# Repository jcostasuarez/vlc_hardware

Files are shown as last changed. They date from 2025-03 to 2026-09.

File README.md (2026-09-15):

# VLC Hardware — Comunicación por Luz Visible

Hardware abierto (KiCad) de una cadena de comunicación por luz visible (VLC):
transmisor óptico, receptor óptico de alta sensibilidad y placas de
acondicionamiento RF. Proyecto final de la carrera de Ingeniería Electrónica,
UTN FRBA.

Cada placa es un módulo independiente que se interconecta con cables coaxiales
SMA de 50 Ω. Todos los proyectos son **autocontenidos**: las huellas y los
símbolos están embebidos y copiados en la biblioteca local de cada proyecto, de
modo que se abren y verifican sin depender de bibliotecas externas.

## Arquitectura

```
Transmisor:   PRE ──► AMP ─┐
                         ├──► LED ──► (espacio libre, luz IR)
              PRE ──► FCA ─┘

Receptor:     PD ──► TIA ──► rx_amp ──► osciloscopio / ADC
```

- **TX**: `PRE` (red de preénfasis) excita a `AMP` **o** a `FCA`; el driver
  elegido alimenta la placa `LED`.
- **RX**: `PD` (fotodiodo + bias) entra a **una sola** placa `TIA`
  (`LMH34400` **o** `LTC6268-10`) y su salida pasa por `rx_amp`.
- **No instalar ambas TIA** en la misma cadena.

Detalle de cableado, alimentación y layout en
[docs/INTEGRACION_MODULAR.md](docs/INTEGRACION_MODULAR.md).

## Placas

| Proyecto | Ruta | Función |
|---|---|---|
| `rx_amp` | `Receiver/AMP/` | Amplificador receptor BGA616, SMA de entrada/salida y alimentación |
| `PD` | `Receiver/PD/` | Adaptador de fotodiodos PDB-C154SM / S5971 / SFH203, SMA y bias |
| `LMH34400` | `Receiver/TIA/LMH34400/` | TIA LMH34400 con entradas PD, salida RF y ALC |
| `LTC6268-10` | `Receiver/TIA/LTC6268-10/` | TIA LTC6268-10 con entrada PD y salida RF |
| `tx_amplifier` | `Transmitter/AMP/` | Amplificador de transmisión con SMA y alimentación de 3,3 V |
| `LumiCom_Transmitter` | `Transmitter/FCA/` | Amplificador/filtro de dos canales con OPA2675 (4 capas) |
| `LED` | `Transmitter/LED/` | Driver/emisor óptico IR, bobina y conectividad RF |
| `preenfasis` | `Transmitter/PRE/` | Red RF de preénfasis (variantes microstrip/CPW) |

## Estructura del repositorio

```
Receiver/AMP/            rx_amp.kicad_{pcb,sch} + library/
Receiver/PD/             PD.kicad_{pcb,sch} + Library/
Receiver/TIA/LMH34400/   LMH34400.kicad_{pcb,sch} + Library/
Receiver/TIA/LTC6268-10/ LTC6268-10.kicad_{pcb,sch} + Library/
Transmitter/AMP/         tx_amplifier.kicad_{pcb,sch} + footprints/
Transmitter/FCA/         LumiCom_Transmitter.kicad_{pcb,sch} + Library/
Transmitter/LED/         LED.kicad_{pcb,sch} + library/
Transmitter/PRE/         preenfasis.kicad_{pcb,sch} + library/
vna/                     Mediciones de red (VNA), calibraciones y scripts de análisis
docs/                    Integración, revisión y evidencias (ERC/DRC)
scripts/                 Exportación reproducible y herramientas de mantenimiento
```

Cada proyecto incluye su `fp-lib-table` y `sym-lib-table` que registran su
biblioteca local (`library/` o `Library/`).

## Requisitos

- [KiCad 10.0.6](https://www.kicad.org/) con `kicad-cli` en el `PATH`
  (variable `KICAD_CLI` para apuntar a otra ruta).
- Python 3 (sólo para las herramientas de `scripts/`).

## Generar revisión y fabricación

```bash
scripts/export_review.sh Receiver/TIA/LTC6268-10
```

Genera en `build/fabrication/<proyecto>/`:

- `erc.rpt`, `drc.rpt` y sus variantes de sólo errores;
- `schematic.pdf`, `layout.pdf`;
- `gerbers/` (Gerber + taladro Excellon);
- `positions.csv` (pick & place);
- `top.png`, `bottom.png` (render 3D) y `layers/board.svg`.

El script **falla** si ERC o DRC reportan errores. Con `STRICT=1` también falla
ante avisos.

## Simulaciones (ngspice)

Todas las simulaciones están unificadas en una única suite **ngspice**,
reproducible y sin GUI (`sim/`):

```bash
scripts/run_all_sims.sh                        # corre todo -> build/sim/
python3 scripts/run_spice.py sim/ltc6268-10/noise.cir --outdir build/sim --noise
python3 scripts/summarize_sims.py build/sim    # métricas -> docs/sim/RESULTS.md
```

`scripts/run_spice.py` usa la `libngspice` que viene con KiCad vía `ctypes`; no
requiere un binario `ngspice`. Incluye respuesta en frecuencia, transitorios y
**análisis de ruido** de las TIA (`lmh34400`, `ltc6268-10`). Los modelos TI
(LMH34400, OPA2675) y el BFR740 corren nativos, con los PSpice convertidos por
`scripts/convert_vendor_model.py`. Los supuestos y la fidelidad de cada deck
están en [sim/README.md](sim/README.md), y los resultados en
[docs/sim/RESULTS.md](docs/sim/RESULTS.md).

Además de cada placa, `sim/system/` interconecta la cadena completa
(`tx_chain`, `tx_chain_fca`, `rx_chain`, `link`, `link_channel`) con interfaces de
50 Ω, incluido el **canal óptico LED → fotodiodo con distancia paramétrica**. El
presupuesto de enlace y cómo ganar alcance están en
[docs/VLC_ALCANCE.md](docs/VLC_ALCANCE.md) (`scripts/vlc_link_budget.py`).

## Estado de revisión

Las ocho placas pasan **ERC y DRC con 0 errores y 0 avisos**, incluyendo DRC con
zonas rellenadas, paridad esquema-placa y paridad de bibliotecas de huellas y
símbolos. Los informes versionados están en
[docs/review/](docs/review/) y el informe completo en
[docs/REVISION_PCB.md](docs/REVISION_PCB.md).

Pendientes antes de fabricar:

1. Confirmar con el fabricante la pila real de 1,2 mm y sus dieléctricos para las
   trayectorias RF (placas `PRE`, `AMP`, TIA y `RX`).
2. Confirmar la decisión de no poblar `JP1` (`Test`) en `LMH34400`.

## Herramientas de mantenimiento

| Script | Uso |
|---|---|
| `scripts/summarize_netlists.py` | Resumen por placa de conectores, rieles y redes de alimentación |
| `scripts/vendor_footprints.py` | Copia las huellas embebidas a la biblioteca local y repunta los FPID |
| `scripts/vendor_symbols.py` | Copia los símbolos embebidos a la biblioteca local y repunta los `lib_id` |
| `scripts/sync_schematic_parity.py` | Sincroniza los campos de huella con el esquema (paridad) |

Todos aceptan modo *dry-run* (sin `--write`).

## Créditos

- Cotti, Nicolás Gabriel — `ncotti@frba.utn.edu.ar`
- UTN FRBA — Proyecto Final de Ingeniería Electrónica

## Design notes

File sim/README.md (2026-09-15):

# Simulaciones ngspice

Suite única de simulación para las placas VLC, reproducible y sin GUI. Reemplaza
las simulaciones dispersas en LTspice (`.asc`) y OrCAD PSpice (`-PSpiceFiles`)
por decks **ngspice** derivados de los esquemas KiCad.

## Cómo correr

```bash
scripts/run_all_sims.sh                        # toda la suite -> build/sim/
python3 scripts/run_spice.py sim/ltc6268-10/noise.cir --outdir build/sim --noise
python3 scripts/summarize_sims.py build/sim    # métricas -> docs/sim/RESULTS.md
```

`scripts/run_spice.py` maneja la `libngspice` que viene con KiCad vía `ctypes`
(no hace falta un binario `ngspice`). Antes de cargar cada deck hace
`set ngbehavior=ltpsa` (compatibilidad PSpice/LTspice). Los resultados van a
`build/sim/` (ignorado por git).

## Estructura

```
sim/models/opamp_2pole.sub        opamp de dos polos (datasheet) [fallback]
sim/models/tia_block.sub          bloque TIA sobre opamp_2pole  [fallback]
sim/models/bfr740l3rh.lib         Infineon BFR740L3RH (nativo)
sim/models/lmh34400.lib           TI LMH34400, convertido a ngspice (nativo)
sim/models/opa2675.lib            TI OPA2675, convertido a ngspice (nativo)
sim/models/bga616.lib             BGA616, bloque de ganancia 50 Ω (datasheet)
sim/<placa>/<análisis>.cir        decks de análisis
```

## Modelos

Los modelos de fabricante son específicos de cada herramienta. Estado por placa:

| Deck | Placa | Modelo | Estado |
|---|---|---|---|
| `preenfasis/filtro_t_ac` | `preenfasis` | RLC puros + puerto 50 Ω | exacto (valores del esquema) |
| `led/bias_t_ac` | `LED` | RLC + equivalente de LED (Li 2019) | exacto (valores del esquema) |
| `tx_amplifier/ac`, `tran` | `tx_amplifier` | Infineon **BFR740L3RH** (Gummel-Poon) | **fabricante, nativo** |
| `lmh34400/ac`, `noise` | `LMH34400` | TI **LMH34400** macro-modelo | **fabricante, convertido** |
| `fca/ac`, `tran` | `LumiCom_Transmitter` | TI **OPA2675** macro-modelo | **fabricante, convertido** |
| `rx_amp/ac` | `rx_amp` | **BGA616** bloque de ganancia 50 Ω | datasheet (sin netlist público) |
| `ltc6268-10/ac`, `noise` | `LTC6268-10` | opamp 2 polos + Rf/Cf | datasheet (ADI solo da LTspice) |

### Conversión de modelos PSpice → ngspice

`scripts/convert_vendor_model.py` traduce los modelos TI (sbom…):

- `.MODEL … VSWITCH ROFF/RON/VOFF/VON` → `.MODEL … SW(Roff/Ron/Vt/Vh)`
- `.MODEL … ISWITCH ROFF/RON/IOFF/ION` → `.MODEL … CSW(Roff/Ron/It/Ih)`
- `PWR(x,y)` → `((x)**(y))`
- descarta `noiseless` y `T_ABS`

Genera `sim/models/lmh34400.lib` y `sim/models/opa2675.lib` desde los `.lib`
originales del repo. Con eso los dos corren 100 % en ngspice y aportan su propio
ruido interno. El LMH34400 reproduce la ganancia integrada de 40 kΩ (≈20 kΩ
entregados a 50 Ω) y el OPA2675 la ganancia cerrada de 4,02.

### Modelos no nativos

- **LTC6268-10**: Analog Devices solo publica el modelo de LTspice, que usa
  devices `A` (OTA/SCHMITT/BUF) y `dnlim/uplim` inexistentes en ngspice. Se usa
  el macromodelo de dos polos de `sim/models/opamp_2pole.sub` con los datos del
  datasheet (GBW 4 GHz, en 4 nV/√Hz, in ≈ 1 fA/√Hz, Cin 1.5 pF).
- **BGA616**: Infineon no publica un netlist; el datasheet solo da el circuito
  equivalente de encapsulado y los parámetros 2G.6. `sim/models/bga616.lib`
  reproduce el comportamiento de gain block de 50 Ω y 19 dB (DC–2,7 GHz).

## Supuestos

- Fotodiodo: `Cd = 1 pF` (condición de datasheet del LMH34400) o `5 pF` en el
  LTC6268-10.
- LMH34400: ALC activo; el contenido bajo ≈400 kHz se rechaza, por eso el ruido
  se integra desde 100 kHz.
- LTC6268-10: `Rf = 3 kΩ`, `Cf = 0.2 pF` (valores del esquema).

## Ruido

`.noise` está en `sim/lmh34400/noise.cir` (modelo TI nativo) y
`sim/ltc6268-10/noise.cir` (macromodelo). `docs/sim/RESULTS.md` reporta densidad
espectral a 1 MHz e integrada sobre la banda.

## Simulación de sistema (interconexión de placas)

Los decks de `sim/system/` encadenan las placas con interfaces de 50 Ω (SMA),
igual que el montaje real:

| Deck | Cadena | Salida analizada |
|---|---|---|
| `tx_chain` | Pitaya (50 Ω) → `preenfasis` → `tx_amplifier` → `LED` (bias-T + LED) | corriente de LED y monitor J2 |
| `tx_chain_fca` | Pitaya → `preenfasis` → `FCA` → `LED` | corriente de LED |
| `rx_chain` | `PD` → `TIA LMH34400` → `rx_amp` | transimpedancia total |
| `rx_chain_noise` | ídem, con `.noise` | ruido de la cadena RX |
| `link` | TX → enlace óptico → RX | ganancia extremo a extremo |
| `link_tran` | ídem, transitorio | respuesta temporal |

Subcircuitos reutilizables en `sim/models/`: `preemphasis.sub`, `tx_amp.sub`,
`fca.sub`, `bias_tee.sub`, `led_equiv.sub`, `rx_amp.sub`. La placa LED entra en
la cadena como **bias-tee** (`BIAS_TEE`: C1/C2 de acople + L1 de polarización)
con el LED como carga (`LED_EQ`). El bias-tee de la placa LED (L1=206 nH, C1/C2=0,1 µF) es un **pasoalto** con
corte ≈1,45 MHz; el corte lo fija el choque L1 (que a baja frecuencia deriva
corriente del LED) y no la banda alta. Barrido de L1 con C=0,1 µF:

| L1 | f_low (−3 dB) |
|---|---:|
| 206 nH | 1,45 MHz |
| 1 µH | 347 kHz |
| 4,7 µH | 85 kHz |
| 10 µH | 51 kHz |
| 47 µH | 33 kHz |

Con L1=10 µH, subir C1/C2 a 1 µF baja el corte a ≈35 kHz (ahí manda el choque).
La banda alta la fijan el LED y el driver, no el choque.

El enlace óptico se modela con una fuente `F` (`I_pd = K · I_LED`), donde `K`
agrupa eficiencia del LED, acoplamiento óptico y responsividad del fotodiodo
(`K = 1e-3` por defecto). Los decks llevan bloqueos de continua para que la
realimentación óptica no altere la polarización.

Resultados destacados (ver `docs/sim/RESULTS.md`):

- `tx_chain`: corriente de LED ≈ 1,0 mA/V pico a ≈52 MHz (con preénfasis y bias-tee).
- `tx_chain_fca`: pico a ≈0,94 MHz — la red R7/C6 de la FCA corta en ≈32 kHz y
  limita el ancho de banda de TX.
- `rx_chain`: ≈7·10⁵ V/A (TIA + rx_amp) con −3 dB en ≈204 MHz.
- `link`: ≈0,68 V/V a 50 MHz con `K = 1e-3`.

> Nota: la FCA tiene dos juegos de valores según el esquema. El netlist raíz
> (`LumiCom_Transmitter.kicad_sch`, usado por el PCB) da R11=402/R9=133; la hoja
> `Amplifier.kicad_sch` da 390/120. El deck usa los del netlist raíz.

## Canal óptico LED ↔ fotodiodo (distancia paramétrica)

`sim/system/optical_channel.cir` modela el enlace óptico LOS (Lambertiano en
eje): `i_pd = K·i_LED`, con `K = G·K0/D²` (ley del cuadrado inverso) y `D` la
distancia en metros (`K0` = fotocorriente/corriente de LED a 1 m; `G` =
ganancia óptica de recolección, p. ej. una lente). El alcance y las mejoras se
analizan en [docs/VLC_ALCANCE.md](../docs/VLC_ALCANCE.md) con
`scripts/vlc_link_budget.py`. La demora `D/c` es solo fase para un canal de frecuencia única y
no cambia la magnitud.

`sim/system/link_channel.cir` es la **cadena completa** con ese canal:
Pitaya → PRE → amplificador discreto → BIAS-TEE → LED → espacio libre (D) →
PD → TIA LMH34400 → rx_amp. Con `D = 0,5 m` da un **canal centrado en 50 MHz**
(≈2,7 V/V a 50 MHz).

Barrido de distancia (`scripts/sweep_optical_distance.py`):

| D [m] | \|Vout/Vin\| @50 MHz | relativo (1/D²) |
|---:|---:|---:|
| 0,10 | 67,7 | 25,0 |
| 0,25 | 10,8 | 4,0 |
| 0,50 | 2,71 | 1,0 |
| 1,00 | 0,677 | 0,25 |
| 2,00 | 0,169 | 0,0625 |

La distancia se cambia con `.param D=<m>` en los dos decks.

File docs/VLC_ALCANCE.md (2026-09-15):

# Alcance del enlace VLC (LED + fotodiodo comerciales)

Con un LED y un fotodiodo baratos, la comunicación sólo funciona con el LED y el
PD casi pegados. El balance de enlace lo explica: con PD desnudo, 10 mA de
modulación y 50 MHz de ancho de banda, un SNR de 10 dB se logra a **≈6 cm**. No
es un problema de "adaptación de impedancia" solamente: es un problema de
**presupuesto óptico y de ruido del receptor**.

`scripts/vlc_link_budget.py` calcula esto (parámetros al inicio del script):

```
LED:  eta=1 W/A, i_led=10 mA, m=1, 850 nm
PD:   R=0.6 A/W, area=1 mm^2, Cj=5 pF
RX:   ruido de entrada 27 pA/√Hz, B=50 MHz
```

| Caso | Distancia para SNR=10 dB |
|---|---:|
| PD desnudo, B=50 MHz | **0,06 m** |
| Lente 25 mm sobre el PD, B=50 MHz | 1,04 m |
| Lente 25 mm, B=10 MHz (canal angosto) | 1,56 m |
| Lente 25 mm, B=1 MHz | 2,77 m |
| Lente 50 mm, B=10 MHz | 3,12 m |
| APD (G≈20) + lente 25 mm, B=10 MHz | 6,97 m |

Regla clave: `i_pd ∝ 1/d²` y por lo tanto **`SNR ∝ 1/d⁴`**. Duplicar la distancia
cuesta 12 dB. Todo lo que sume dB en el presupuesto óptico rinde mucho.

## Prioridades para ganar distancia

1. **Óptica en el receptor (lo de mayor impacto).** Una lente delgada sobre el
   PD concentra la luz; la ganancia ≈ `(D_lente/d_PD)²·η`. Una lente de 25 mm
   sobre un PD de 1 mm² da **+25 dB**; 50 mm, +31 dB. Hay que **alinear** y que
   el ángulo de emisión del LED entre en el campo de visión del PD. Un
   concentrador tipo CPC o un reflector parabólico son alternativas.
2. **Filtrado y receptor angosto.** Un filtro óptico pasa-banda IR (o rojo)
   delante del PD rechaza luz ambiente. Del lado eléctrico, un **filtro
   pasa-banda en la portadora** reduce el ruido fuera de banda: el ruido cae con
   `√B`, así que pasar de 50 MHz a 1 MHz mejora ~17 dB. Para un canal de 50 MHz
   centrado en una portadora, usar un receptor resonante.
3. **Más luz del LED, más directiva.** Subir la corriente de modulación (límite
   térmico), usar un LED **IR 850/940 nm** (mejor acople con un PD de Si que un
   LED blanco de fósforo) y un LED de **haz angosto** (mayor orden lambertiano
   `m`: la intensidad en eje crece con `m+1`).
4. **Menos ruido en el receptor.** El ruido de entrada del TIA es el que fija el
   mínimo detectable. Conviene un **TIA CMOS de baja corriente de ruido** (el
   `LTC6268-10` es CMOS; el `LMH34400` es bipolar, más ruidoso en corriente) y
   **maximizar la transimpedancia** (subir `Rf`, o usar la ganancia integrada de
   40 kΩ del LMH34400) hasta donde el ancho de banda lo permita.
5. **Minimizar la capacidad del PD.** PD más chico (o con polarización inversa)
   y **PD y TIA pegados** (pistas cortas, sin cable SMA entre medio). La
   capacidad del PD es la que fija el ancho de banda y el ruido del TIA:
   `B ∝ 1/(Rf·C)` y `ruido ∝ √C`. Hay un compromiso **sensibilidad ↔ ancho de
   banda**.

## ¿Falta adaptar alguna impedancia?

Sí, pero **no con el paradigma de 50 Ω**:

- **TX (LED):** el LED es de baja impedancia y no lineal (≈1–5 Ω). Adaptar el
  driver a 50 Ω **desperdicia potencia**. Lo correcto es un **driver de corriente**
  o una red de adaptación (LC o transformador) que transforme los 50 Ω del driver
  a los pocos ohmios del LED, para que más corriente de modulación llegue al LED.
  La placa LED ya tiene el bias-tee (`L1` + `C1`/`C2`); ajustá `L1`/`C1` para la
  banda.
- **RX (PD → TIA):** el PD es una fuente de corriente capacitiva y la entrada del
  TIA es tierra virtual; no se "matchea a 50 Ω". Lo que ayuda es:
  - **resonar la capacidad del PD** con un inductor en paralelo (o red LC) en la
    portadora → sube la impedancia de entrada justo en la frecuencia útil
    (canal angosto);
  - **inductive peaking / T-coil** para extender el ancho de banda;
  - **cortar el cable SMA** entre PD y TIA (cada cm de cable suma capacidad y
    reflexiones).

En `sim/system/link_channel.cir` y `optical_channel.cir` la ganancia óptica está
parametrizada: `.param G=<lente>` (por defecto 1). Con `G=344` (lente de 25 mm)
el enlace mejora 25 dB y el alcance escala con `√G`.

## Qué tocaría en estas placas

1. Agregar **lente/concentrador** y filtro óptico IR en la placa PD.
2. **Pegar el PD al TIA** (misma placa o conexión cortísima) y bajar `Cd`
   (polarizar el PD).
3. En recepción, para un canal angosto de 50 MHz, agregar **red resonante** en la
   entrada del TIA y un **pasa-banda** a la salida (antes del `rx_amp`).
4. En transmisión, usar la **FCA/OPA2675 como driver de corriente** con red de
   adaptación al LED (no 50 Ω directo) y preénfasis digital en la Red Pitaya.
5. Si hace falta más alcance, **APD** (ganancia interna) o un PD pre-amplificado.

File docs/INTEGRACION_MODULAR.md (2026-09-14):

# Integración modular VLC

## Arquitectura y selección

La cadena de transmisión es `PRE` -> `AMP` **o** `FCA` -> `LED`.  La cadena de
recepción es `PD` -> **una sola** placa `TIA` (`LMH34400` **o** `LTC6268-10`)
-> `rx_amp` -> instrumento/ADC.

No instalar ambas TIA en la misma cadena.  La selección se realiza antes de
cablear: los componentes, los valores y los jumpers de cada variante se
conservan tal como están en sus esquemas.  En particular, no se ha supuesto una
impedancia de pista ni una pila de fabricación que el fabricante no haya
confirmado.

## Cableado entre módulos

Usar cables coaxiales SMA de 50 ohmios, cortos, exclusivamente para señal RF.
Conectar primero todos los retornos de chasis/GND y las borneras de alimentación,
y después los SMA con la alimentación desconectada.  Nunca aplicar tensión DC a
un SMA.

1. Conectar la salida SMA de PRE a la entrada SMA de AMP o FCA.
2. Conectar la salida SMA del driver elegido a la entrada SMA de la placa LED.
3. En recepción, conectar el SMA de la placa PD al SMA de entrada de la TIA
   elegida; conectar la salida RF de esa TIA a la entrada de `rx_amp`.
4. Conectar la salida SMA de `rx_amp` al osciloscopio de 50 ohmios o al ADC que
   presente la terminación especificada por el diseño.

Cada bornera se reserva para alimentación/bias y GND; comprobar polaridad contra
la serigrafía y el esquema antes de energizar.  `tx_amplifier` etiqueta su rail
como `+3.3V`. Las demás placas etiquetan sus rails como `VCC`, `Vdc` o `Vout`:
la tensión numérica, corriente disponible y polaridad en J1/J3/J5 deben
confirmarse contra la revisión de esquema y la hoja de datos del componente que
alimente la placa. No se ha inferido ninguna de esas tensiones.

## Notas de layout y montaje

- Mantener el plano de GND continuo bajo RF; no dejar stubs ni añadir vías en la
  ruta RF sin recalcular la impedancia para la pila real.
- Añadir vías de cosido GND junto a SMA/CPW sólo tras confirmar el stack-up,
  diámetro de vía y separación del fabricante.
- En PD/TIA, montar el fotodiodo y el TIA contiguos; mantener el nodo de entrada
  de alta impedancia corto, limpio y separado de la salida RF y del LED.
- En LED, el lazo `bornera -> L1 -> LED -> GND` debe ser compacto y de cobre
  acorde a la corriente de LED validada. Los conectores J1/J2 están acoplados
  por C1/C2; la alimentación entra por J3, no por SMA.
- La placa LED contiene las opciones LED1 (SFH 47167B) y LED2
  (XPERED-L1-0000-00501). La documentación disponible no establece cuál debe
  montarse ni si una debe quedar DNP; no poblar ambas sin confirmación de la
  configuración óptica y de corriente.

## Estado de revisión

Los informes de DRC/ERC versionados están en `docs/review/` y el informe completo
en `docs/REVISION_PCB.md`. Se eliminó un arco de cobre colgante en
`Receiver/TIA/LTC6268-10`; su respaldo local está en `build/backups/2026-09-14/`.

La placa LED tenía dos errores ERC de metadatos de símbolo: GND no declaraba la
fuente externa y los cátodos de LEDs se definieron como salidas. Ambos se
corrigieron en `Transmitter/LED/LED.kicad_sch` (cátodo `passive` y `PWR_FLAG`
sobre GND).

Las bibliotecas de huellas y de símbolos quedaron consolidadas: cada proyecto es
autocontenido y las definiciones embebidas se copiaron verbatim a la biblioteca
local de su proyecto. Se limpió además la paridad esquema-placa sincronizando los
campos de la huella con el esquema. Las herramientas son
`scripts/vendor_footprints.py`, `scripts/vendor_symbols.py` y
`scripts/sync_schematic_parity.py`; los respaldos de cada paso se conservan
localmente (no versionados) en `build/backups/2026-09-14-*`.

Las ocho placas dan ERC y DRC con 0 errores y 0 avisos. Pendiente de fabricación:
confirmar la pila RF de 1,2 mm y la decisión de no poblar JP1 en `LMH34400`; ver
`docs/REVISION_PCB.md`.

## Cadena de excitación del LED (recomendación)

La cadena propuesta —Pitaya → preénfasis → FCA → amplificador discreto → LED— se
puede simplificar y conviene ajustarla:

1. **Un solo driver.** Encadenar FCA + `tx_amplifier` suma ruido y distorsión y
   recorta banda. La simulación de sistema lo muestra: con el amplificador
   discreto la corriente de LED pica a ≈52 MHz; con la FCA pica a ≈0,94 MHz,
   porque su red de entrada R7/C6 (49,9 Ω / 0,1 µF) corta en ≈32 kHz.
2. **Preénfasis una sola vez.** Mejor en digital dentro de la FPGA de la Red
   Pitaya (ajustable, sin dispersión de componentes) y dejar una única etapa
   analógica de adaptación. Si se hace en analógico, usar el filtro `PRE` y no
   repetirlo.
3. **El bias-tee va en la placa LED** (`J3 → L1 → nodo del LED`, con `C1`/`C2`
   acoplando `J1`/`J2`). Es la forma correcta de sumar polarización DC y RF. Con
   los valores de la placa (L1=206 nH, C=100 nF) es un pasoalto con corte
   ≈1,45 MHz, fijado por el choque; para bajarlo, L1=4,7–10 µH y C≥1 µF
   (≈85 kHz). La banda alta la fijan el LED y el driver. El último estado del driver debe ser de corriente con polarización DC. Un
   LED común necesita decenas a cientos de mA y tiene impedancia dinámica de
   pocos ohmios (≈1–5 Ω). Un amplificador de tensión adaptado a 50 Ω entrega muy
   poca corriente de modulación (≈1 mA/V según la simulación). Usar el lazo
   `bornera → L1 → LED → GND` de la placa LED como bias-T y un driver con
   capacidad de corriente: la **FCA (OPA2675)** tiene la salida de corriente para
   esto; el **`tx_amplifier` (BFR740L3RH)** es un transistor de RF pequeño, sirve
   como pre-driver, no como driver de potencia.
4. **Límites reales del LED.** El ancho de banda de un LED común lo fijan el
   tiempo de vida de portadores y el RC (unos pocos a decenas de MHz). El
   preénfasis extiende el −3 dB a costa de rango dinámico; para más velocidad
   conviene un LED azul/IR de baja capacidad o un láser.
5. **Validar contra mediciones.** El repositorio ya tiene 74 mediciones `.s2p`
   en `vna/`; conviene superponerlas con las respuestas simuladas (`sim/system`).

Cadena recomendada:

```
Red Pitaya (preénfasis digital en FPGA)
   └─ 50 Ω ─► [PRE analógico opcional] ─► driver DC (FCA/OPA2675)
        └─ bias-T (L1) + acople (C1) ─► LED
Rx: PD ─► TIA (LMH34400) ─► rx_amp ─► ADC/osciloscopio
```

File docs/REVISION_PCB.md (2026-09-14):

# Revisión de PCB — 2026-09-14

## Alcance y método

Se revisaron las ocho placas nativas del repositorio con KiCad 10.0.6. El DRC
se ejecutó con zonas rellenadas y paridad esquema-placa; los informes versionados
están en `docs/review/drc` (ERC en `docs/review/erc`). Los avisos de biblioteca
se contabilizan por separado de los defectos físicos.

| Placa | Función | ERC | DRC | Estado |
|---|---|---:|---:|---|
| `Receiver/AMP/rx_amp` | Amplificador receptor BGA616, SMA de entrada/salida y alimentación | 0 | 0 | Limpia |
| `Receiver/PD/PD` | Adaptador de fotodiodos PDB-C154SM / S5971 / SFH203, SMA y bias | 0 | 0 | Limpia |
| `Receiver/TIA/LMH34400` | TIA LMH34400 con entradas PD, salida RF y ALC | 0 | 0 | Limpia |
| `Receiver/TIA/LTC6268-10` | TIA LTC6268-10 con entrada PD y salida RF | 0 | 0 | Limpia |
| `Transmitter/AMP/tx_amplifier` | Amplificador de transmisión con SMA y alimentación de 3,3 V | 0 | 0 | Limpia |
| `Transmitter/FCA/LumiCom_Transmitter` | Amplificador/filtro de dos canales con OPA2675; 4 capas | 0 | 0 | Limpia |
| `Transmitter/LED/LED` | Driver/emisor óptico IR, bobina y conectividad RF | 0 | 0 | Limpia |
| `Transmitter/PRE/preenfasis` | Red RF de preénfasis, variantes microstrip/CPW | 0 | 0 | Limpia |

Las ocho placas pasan ERC y DRC con **0 errores y 0 avisos**, incluyendo DRC con
zonas rellenadas, paridad esquema-placa, paridad de bibliotecas de huellas y de
símbolos, y ERC completo.

## Mejoras aplicadas

1. En `Receiver/TIA/LTC6268-10/LTC6268-10.kicad_pcb` se eliminó, mediante la API
   de KiCad, un arco aislado de F.Cu de 0,1341 mm en `Net-(J1-In)`. Era el único
   aviso de cobre funcional (`track_dangling`). La copia previa está en el
   respaldo local `build/backups/2026-09-14/LTC6268-10.kicad_pcb.before-dangling-arc-removal`.
2. En la misma placa se movió el texto de serigrafía `OUT` (F.SilkS) de
   (129,92; 64,50) a (134,42; 65,00) mm para despejar el designador de R3. Sólo
   cambió la posición del texto: ni cobre ni red ni huella.
3. En `Transmitter/LED/LED.kicad_sch` se corrigieron los dos errores ERC de
   metadatos: el cátodo del LED dejó de declararse `output` (ahora `passive`) y
   se añadió un `power:PWR_FLAG` sobre GND, coherente con el resto de esquemas.
4. **Consolidación de bibliotecas de huellas.** Cada una de las ocho placas se
   hizo autocontenida: se extrajo la huella embebida exacta de cada componente y
   se copió a la biblioteca local del proyecto, repuntando el FPID de la placa y
   el campo Footprint del símbolo. Se vendieron 56 tipos de huella; 20 instancias
   estaban ausentes de las bibliotecas instaladas (dos tipos: la SMA
   `SMA_Samtec_SMA-J-P-X-ST-EM1_EdgeMount` y la bornera
   `TerminalBlock_bornier-2_P5.08mm`). Los avisos `lib_footprint_mismatch`
   (110) y `lib_footprint_issues` (20) quedaron en 0. La huella, pads, redes,
   zonas y modelos 3D se copiaron verbatim: los conteos de `footprint`, `pad`,
   `segment`, `via`, `zone`, `gr_line`, `gr_poly`, `gr_text` y `dimension` son
   idénticos a los respaldos, y la estructura de los esquemas no cambió.
5. **Consolidación de bibliotecas de símbolos.** Se aplicó el mismo criterio a
   los esquemas: la definición de símbolo embebida en `lib_symbols` se copió a la
   biblioteca local del proyecto y se repuntó el `lib_id` y el nombre del símbolo
   embebido. Se vendieron 77 referencias de símbolo (23 tipos, entre ellos
   `Connector:Conn_Coaxial`, `Device:C_Small` y varios `power`, más
   `Device:Q_NPN_BCE`, ausente de la biblioteca instalada de KiCad 10). Los
   avisos `lib_symbol_mismatch` (65) y `lib_symbol_issues` (1) quedaron en 0: las
   ocho placas dan **ERC con 0 errores y 0 avisos**. Sólo cambiaron `lib_id` y
   los nombres en `lib_symbols`; los conteos de `symbol`, `wire`, `junction`,
   `label`, `pin`, `polyline` y `text` son idénticos a los respaldos.
6. **Limpieza de paridad esquema-placa.** Se sincronizaron los campos de la
   huella con el esquema (fuente de verdad): 52 campos en 6 placas, en su mayoría
   espacios sobrantes en `Description`/`Datasheet`, más el `Value` de L1/L3/D1.
   Se completó además el `Manufacturer`/`Manufacturer Part Number`/`Mouser Part
   Number` de JP1 en `LTC6268-10`. Los 49 avisos `footprint_symbol_mismatch` y
   `footprint_symbol_field_mismatch` quedaron en 0. Sólo cambiaron valores de
   campos; los conteos físicos y de propiedades son idénticos a los respaldos.
   Para el único aviso restante de atributo, JP1 (jumper de prueba) en
   `LMH34400`, se marcó `dnp yes` en el esquema para que coincida con la huella
   DNP de la placa y se conserve el comportamiento de no poblar.

Herramientas: `scripts/vendor_footprints.py`, `scripts/vendor_symbols.py` y
`scripts/sync_schematic_parity.py`. Los respaldos de cada paso se conservan
localmente (no versionados) en `build/backups/2026-09-14-*`.

Los cambios están verificados con KiCad 10.0.6: las ocho placas dan ERC y DRC con
0 errores y 0 avisos.

## Pendientes antes de fabricar

1. Para las trayectorias RF, confirmar con el fabricante la pila real de 1,2 mm
   y sus dieléctricos. Las placas PRE, AMP, TIA y RX usan SMA y/o trazas RF; la
   impedancia no debe inferirse solamente de la anotación de FR-4.
2. Confirmar la decisión de no poblar JP1 (`Test`) en `LMH34400`; quedó DNP en
   placa y esquema para conservar el estado actual.

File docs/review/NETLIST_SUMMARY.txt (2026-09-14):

### LED (11 comps, 5 nets)
Connectors:
  J1     RFPC-SMA28-F                             LumiCom_Led:RFPC-SMA28-F
  J2     RFPC-SMA28-F                             LumiCom_Led:RFPC-SMA28-F
  J3     Vdc                                      LumiCom_Led:TerminalBlock_Phoenix_MKDS-1,5-2_1x02_P5.00mm_Horizontal
Power nets:
  GND                  -> J1, J2, J3, LED1, LED2
  Net-(J1-In)          -> C1, J1
  Net-(J2-In)          -> C2, J2
  Net-(J3-Pin_2)       -> J3, L1

### LMH34400 (24 comps, 14 nets)
Connectors:
  J1     TEST                                     LumiCom_TIA:SMA_Samtec_SMA-J-P-X-ST-EM1_EdgeMount
  J2     PD IN                                    LumiCom_TIA:SMA_Samtec_SMA-J-P-X-ST-EM1_EdgeMount
  J3     Vout                                     LumiCom_TIA:TerminalBlock_Phoenix_MKDS-1,5-2_1x02_P5.00mm_Horizontal
  J4     N_EN                                     LumiCom_TIA:PinHeader_1x03_P2.54mm_Vertical
  J5     N_ALC                                    LumiCom_TIA:PinHeader_1x03_P2.54mm_Vertical
  J6     OUT                                      LumiCom_TIA:SMA_Samtec_SMA-J-P-X-ST-EM1_EdgeMount
  JP1    Test                                     LumiCom_TIA:R_0603_1608Metric_Pad0.98x0.95mm_HandSolder
Power nets:
  GND                  -> C1, C3, C4, C5, J1, J2, J3, J4, J5, J6, R3, U1
  Net-(J1-In)          -> C2, J1, R1
  Net-(J2-In)          -> J2, JP1, U1
  Net-(J3-Pin_2)       -> J3, L1
  Net-(J4-Pin_2)       -> J4, U1
  Net-(J5-Pin_2)       -> J5, U1
  Net-(J6-In)          -> C6, J6, R5
  Net-(JP1-A)          -> JP1, R2
  VCC                  -> C3, C4, C5, D1, J4, J5, L1, U1

### LTC6268-10 (29 comps, 14 nets)
Connectors:
  J1     IN                                       LumiCom_TIA:SMA_Samtec_SMA-J-P-X-ST-EM1_EdgeMount
  J2     Vout                                     LumiCom_TIA:TerminalBlock_Phoenix_MKDS-1,5-2_1x02_P5.00mm_Horizontal
  J3     TEST                                     LumiCom_TIA:SMA_Samtec_SMA-J-P-X-ST-EM1_EdgeMount
  J4     OUT                                      LumiCom_TIA:SMA_Samtec_SMA-J-P-X-ST-EM1_EdgeMount
  JP1    Test                                     LumiCom_TIA:R_0603_1608Metric_Pad0.98x0.95mm_HandSolder
Power nets:
  GND                  -> C1, C2, C4, C5, C6, J1, J2, J3, J4, R4, R5, SD_L1, U1
  Net-(J1-In)          -> Cf1, Cf2, J1, JP1, Rf1, U1
  Net-(J2-Pin_2)       -> J2, L1
  Net-(J3-In)          -> C3, J3, R1
  Net-(J4-In)          -> C7, J4, R7
  Net-(JP1-A)          -> JP1, R2
  VCC                  -> C2, C4, C5, D1, L1, R3, SD_L1, U1

### LumiCom_Transmitter (38 comps, 22 nets)
Connectors:
  J1     V                                        LumiCom_Transmitter:TerminalBlock_Phoenix_MKDS-1,5-2_1x02_P5.00mm_Horizontal
  J2     IN_B                                     LumiCom_Transmitter:SMA_Samtec_SMA-J-P-X-ST-EM1_EdgeMount
  J3     IN_A                                     LumiCom_Transmitter:SMA_Samtec_SMA-J-P-X-ST-EM1_EdgeMount
  J4     OUT_B                                    LumiCom_Transmitter:SMA_Samtec_SMA-J-P-X-ST-EM1_EdgeMount
  J5     OUT_A                                    LumiCom_Transmitter:SMA_Samtec_SMA-J-P-X-ST-EM1_EdgeMount
Power nets:
  GND                  -> C1, C11, C2, C5, C6, C7, C8, J1, J2, J3, J4, J5, JP_A0, JP_A1, R2, R5, R6, U1
  Net-(J1-Pin_1)       -> J1, L1
  Net-(J2-In)          -> C3, J2
  Net-(J3-In)          -> C4, J3
  Net-(J4-In)          -> J4, R14
  Net-(J5-In)          -> J5, R13
  Net-(JP_A0-C)        -> JP_A0, U1
  Net-(JP_A1-C)        -> JP_A1, U1
  VCC                  -> C1, C2, C7, D1, JP_A0, JP_A1, L1, R1, R4, U1

### PD (9 comps, 6 nets)
Connectors:
  J2     RFPC-SMA28-F                             Lumicom_Photodiode:RFPC-SMA28-F
  J3     RFPC-SMA28-F                             Lumicom_Photodiode:RFPC-SMA28-F
  J4     RFPC-SMA28-F                             Lumicom_Photodiode:RFPC-SMA28-F
  J5     Screw_Terminal_01x02                     Lumicom_Photodiode:TerminalBlock_bornier-2_P5.08mm
Power nets:
  GND                  -> C1, D1, J2, J3, J4, J5
  Net-(J3-In)          -> D2, J3
  Net-(J5-Pin_2)       -> J5, L1

### preenfasis (24 comps, 12 nets)
Connectors:
  J1     SMA H                                    preenfasis:SMA_Samtec_SMA-J-P-X-ST-EM1_EdgeMount
  J2     SMA H                                    preenfasis:SMA_Samtec_SMA-J-P-X-ST-EM1_EdgeMount
  J3     SMA H                                    preenfasis:SMA_Samtec_SMA-J-P-X-ST-EM1_EdgeMount
  J4     SMA H                                    preenfasis:SMA_Samtec_SMA-J-P-X-ST-EM1_EdgeMount
Power nets:
  Net-(J1-Ext)         -> C2, J1, J2, L2
  Net-(J1-In)          -> C1, J1, R1, R3
  Net-(J2-In)          -> J2, L1, R1, R4
  Net-(J3-Ext)         -> C4, J3, J4, L4
  Net-(J3-In)          -> C3, J3, R5, R7
  Net-(J4-In)          -> J4, L3, R5, R8

### rx_amp (13 comps, 9 nets)
Connectors:
  J1     Signal_In                                rx_amp:SMA_Samtec_SMA-J-P-X-ST-EM1_EdgeMount
  J2     Signal_Out                               rx_amp:SMA_Samtec_SMA-J-P-X-ST-EM1_EdgeMount
  J3     Screw_Terminal_01x02                     rx_amp:TerminalBlock_RND_205-00001_1x02_P5.00mm_Horizontal
Power nets:
  GND                  -> C3, IC1, J1, J2, J3
  Net-(J1-In)          -> C1, J1
  Net-(J2-In)          -> C2, J2
  Net-(J3-Pin_2)       -> J3, L3

### tx_amplifier (20 comps, 10 nets)
Connectors:
  J1     Conn_Coaxial                             vlc:SMA_Samtec_SMA-J-P-X-ST-EM1_EdgeMount
  J2     Conn_Coaxial                             vlc:SMA_Samtec_SMA-J-P-X-ST-EM1_EdgeMount
  J3     Screw_Terminal_01x02                     vlc:TerminalBlock_bornier-2_P5.08mm
Power nets:
  +3.3V                -> J3, R1
  GND                  -> C2, C3, C4, J1, J2, J3, Q1
  Net-(J1-In)          -> C1, J1
  Net-(J2-In)          -> C5, J2

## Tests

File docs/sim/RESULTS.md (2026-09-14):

# Resultados de simulación (ngspice)

Generado por `scripts/summarize_sims.py` (2026-09-14).
Supuestos de los modelos en `sim/README.md`.

## Respuesta en frecuencia (AC)

| Deck | Banda simulada | Pico | Frecuencia del pico | Ancho de banda a -3 dB |
|---|---|---:|---:|---:|
| `fca` | 1e+04..5e+09 Hz | 0.936 | 3.47e+04 Hz | 8.35e+04 Hz |
| `led__bias_t` | 1e+05..1e+10 Hz | 0.459 | 1e+10 Hz | > banda |
| `lmh34400` | 1e+03..1e+09 Hz | 2.16e+04 | 2e+06 Hz | 2.19e+08 Hz |
| `ltc6268-10` | 1e+03..1e+09 Hz | 1.5e+03 | 7.41e+03 Hz | 7.59e+07 Hz |
| `preenfasis__filtro_t` | 1e+05..5e+08 Hz | 0.5 | 5.22e+07 Hz | 8.28e+07 Hz |
| `rx_amp` | 1e+05..1e+10 Hz | 8.9 | 8.91e+09 Hz | > banda |
| `system__link` | 1e+03..1e+09 Hz | 0.682 | 5.25e+07 Hz | 8.71e+07 Hz |
| `system__link_channel` | 0.001..1e+09 Hz | 2.73 | 5.25e+07 Hz | 8.71e+07 Hz |
| `system__optical_channel` | 0.001..1e+09 Hz | 0.004 | 0.001 Hz | > banda |
| `system__rx_chain` | 1e+03..1e+09 Hz | 7.02e+05 | 2.09e+06 Hz | 2.04e+08 Hz |
| `system__tx_chain` | 1e+04..1e+09 Hz | 0.00101 | 5.25e+07 Hz | 8.51e+07 Hz |
| `system__tx_chain_fca` | 1e+04..1e+09 Hz | 0.00085 | 1.32e+06 Hz | 2.75e+06 Hz |
| `tx_amplifier` | 1e+03..1e+10 Hz | 6.65 | 1.51e+04 Hz | 4.84e+08 Hz |

## Transitorio

| Deck | pico-pico |
|---|---:|
| `fca` | 0.00761 V |
| `system__link` | 0.0134 V |
| `tx_amplifier` | 0.00884 V |

## Ruido

| Deck | en salida @1 MHz | in referida @1 MHz | en salida rms (banda) | in referida rms (banda) |
|---|---:|---:|---:|---:|
| `lmh34400` | 5.48e-07 V/√Hz | 2.68e-11 A/√Hz | 0.0242 V | 2.06e-06 A |
| `ltc6268-10` | 6.74e-09 V/√Hz | 4.49e-12 A/√Hz | 0.000335 V | 2.29e-06 A |
| `system__rx_chain_noise` | 1.76e-05 V/√Hz | 2.68e-11 A/√Hz | 0.755 V | 2.06e-06 A |

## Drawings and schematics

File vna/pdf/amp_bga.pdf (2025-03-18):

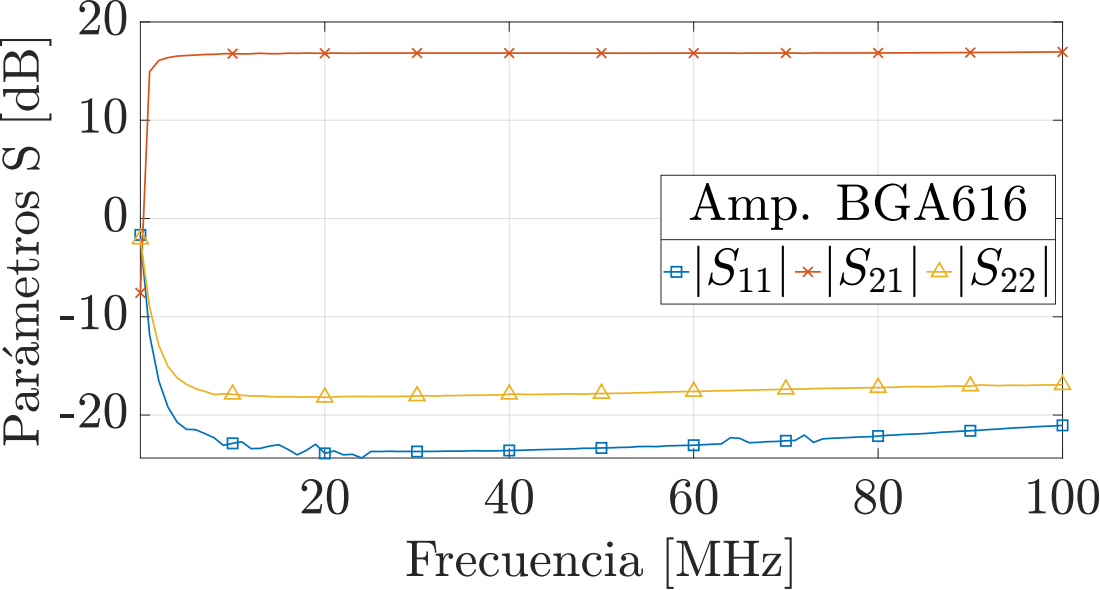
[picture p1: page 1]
0 Par4ametros S [dB] jS; 2j Amp. BGA616

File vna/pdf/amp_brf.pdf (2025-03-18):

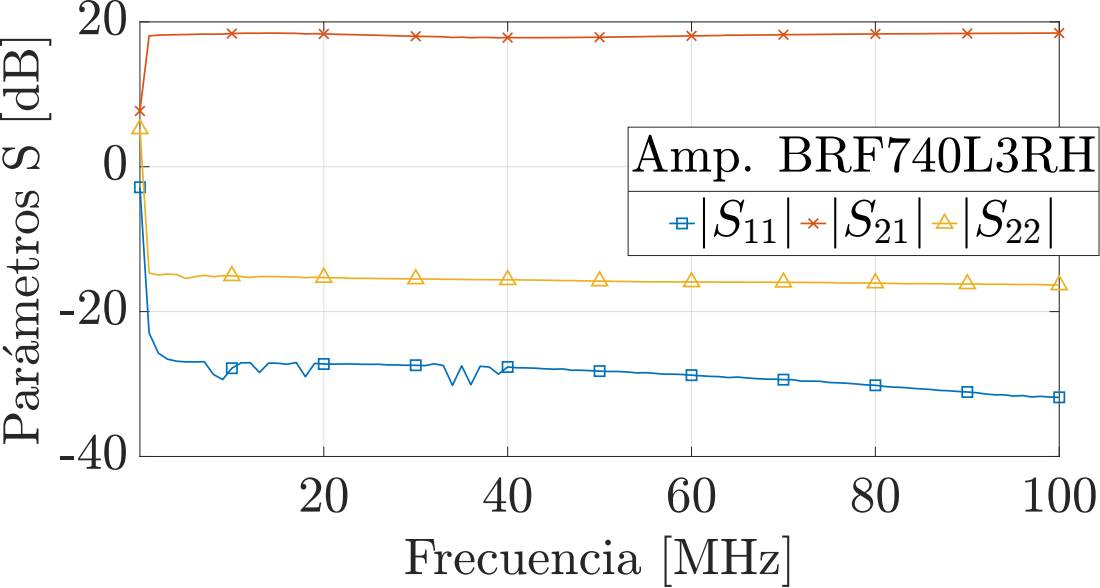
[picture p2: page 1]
0 Par4ametros S [dB] jS; 2j Amp. BRF740L3R

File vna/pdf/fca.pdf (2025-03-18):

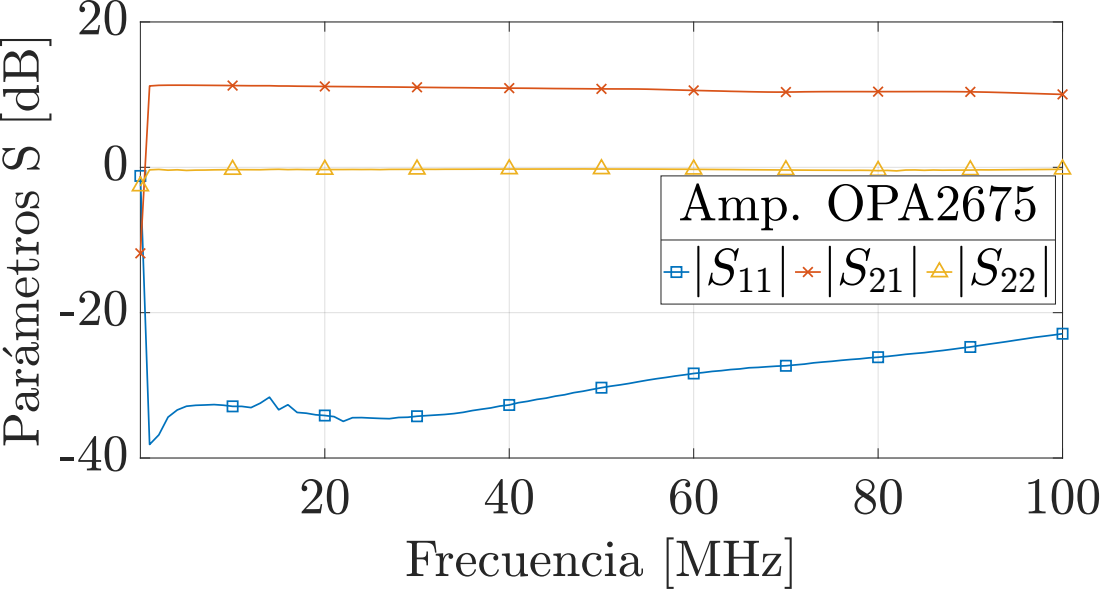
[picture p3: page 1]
0 Par4ametros S [dB] jS; 2j Amp. OPA2675

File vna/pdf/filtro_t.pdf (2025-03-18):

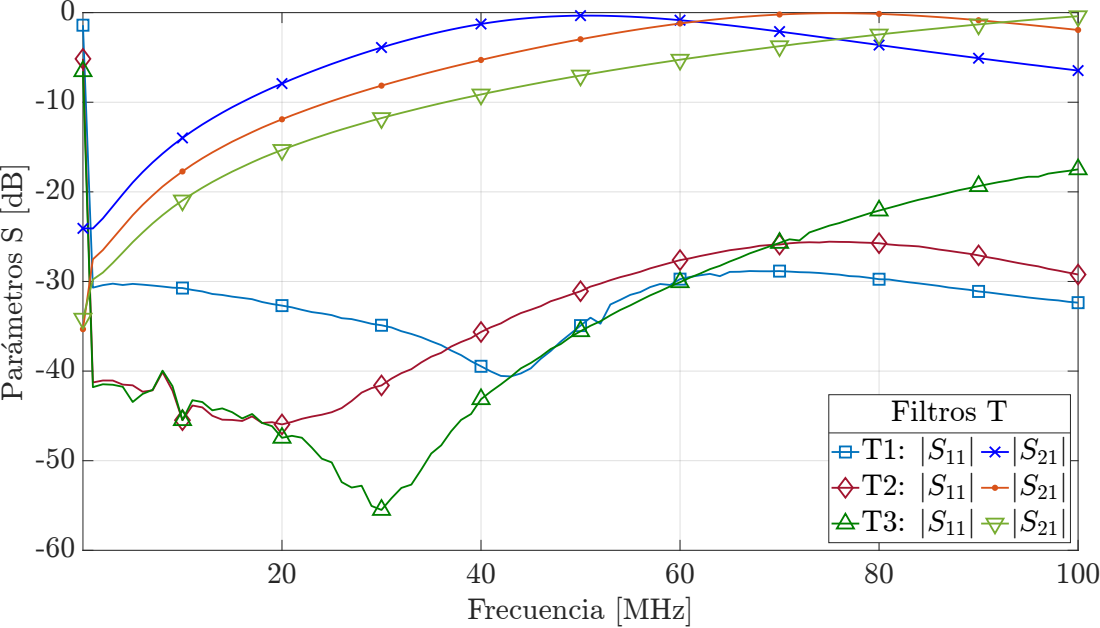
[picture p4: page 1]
Par4ametros S [dB]

T | 1j jS21j jS21j Filtros T 1: jS 1 2
1j T2: jS11j T3: jS11j jS

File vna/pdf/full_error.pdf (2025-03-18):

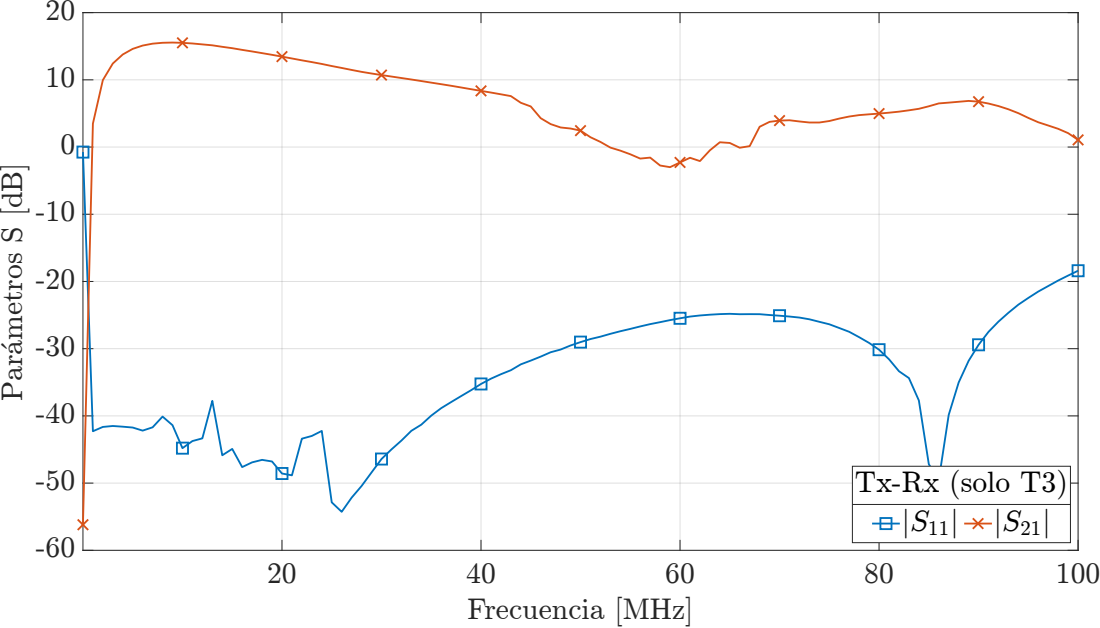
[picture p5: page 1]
Par4ametros S [dB] jS

1j Tx-Rx (solo T3 1j jS 1 2

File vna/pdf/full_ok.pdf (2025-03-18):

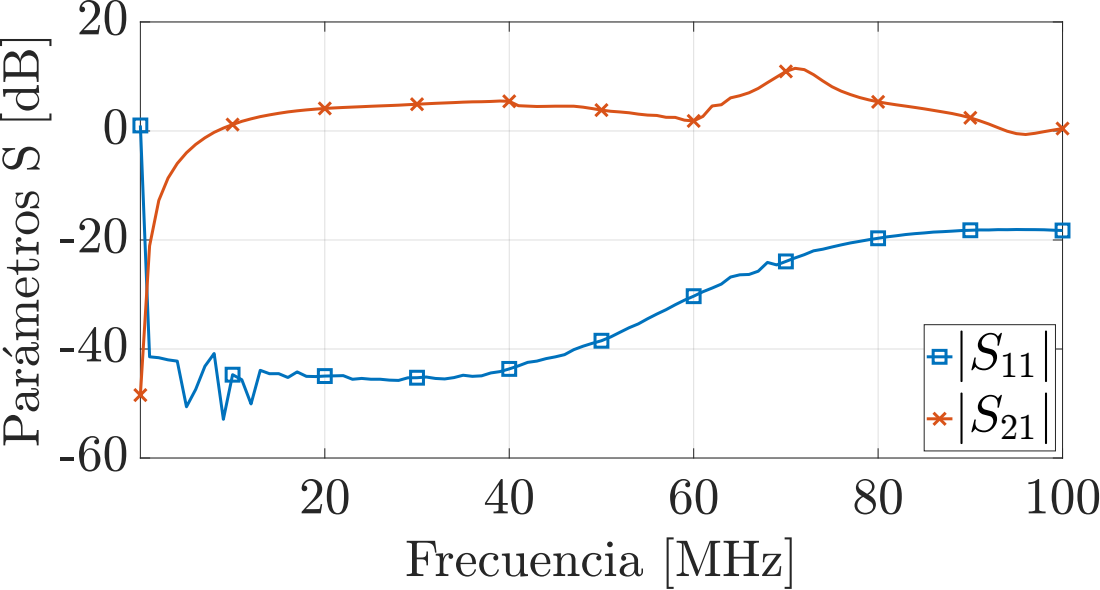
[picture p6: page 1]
0 Par4ametros S [dB] jS

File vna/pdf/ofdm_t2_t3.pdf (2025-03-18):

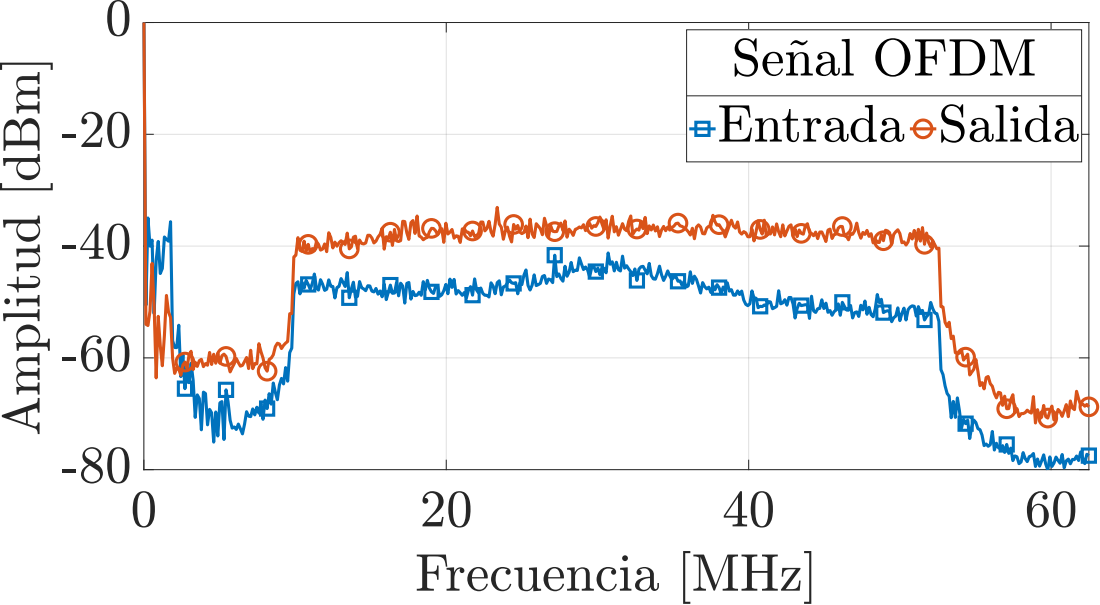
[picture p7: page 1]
Amplitud [dBm]

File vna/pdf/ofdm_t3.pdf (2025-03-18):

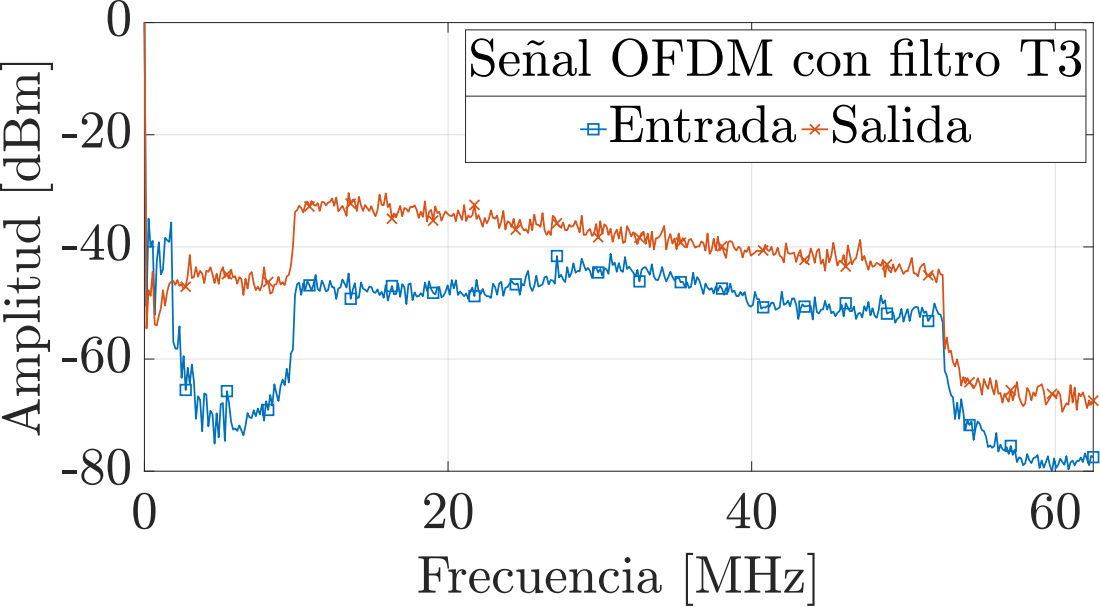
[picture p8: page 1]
Amplitud [dBm]

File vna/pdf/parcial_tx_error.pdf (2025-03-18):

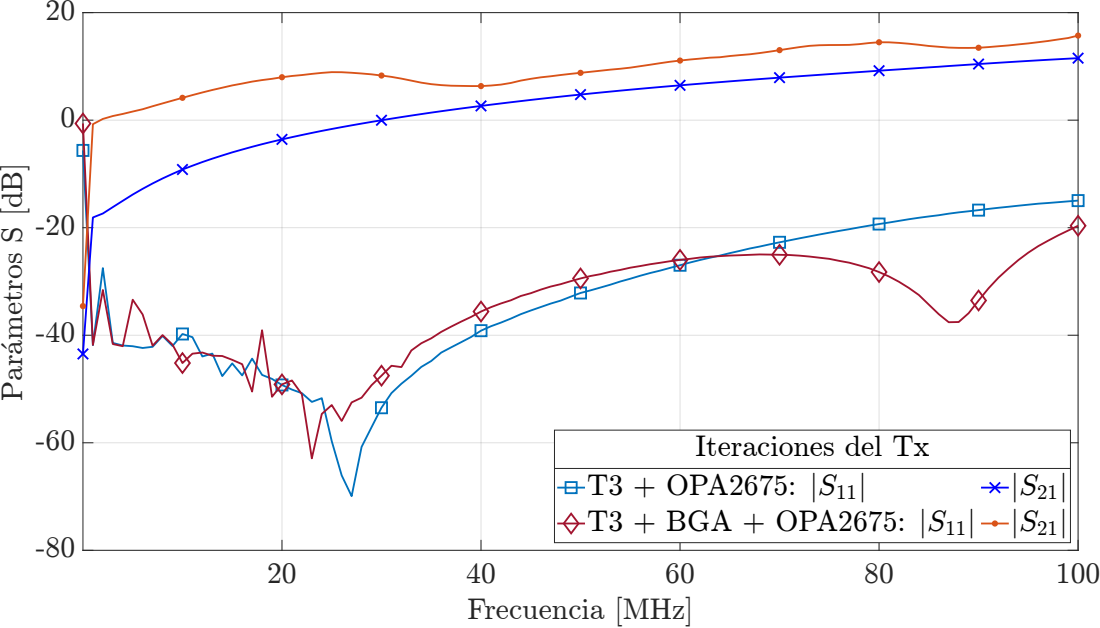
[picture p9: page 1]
Par4ametros S [dB]; 1j T3 + BGA + OPA26 7; 1j jS21j Iteraciones del Tx

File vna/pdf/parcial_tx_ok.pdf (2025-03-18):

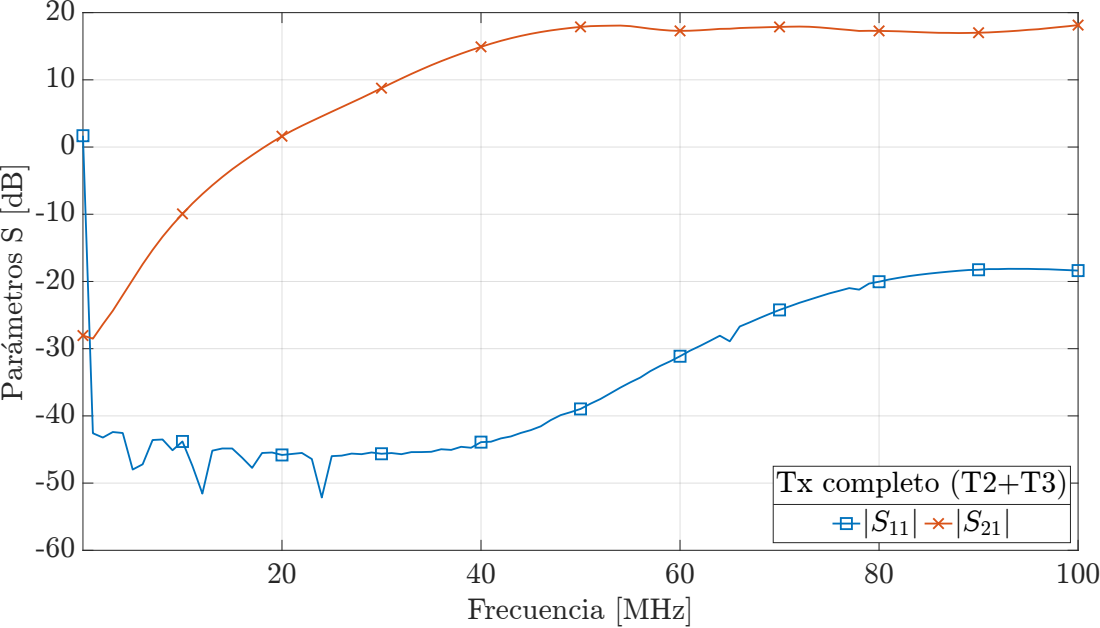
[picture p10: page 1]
Par4ametros S [dB] jS

1j Tx completo (T2+ 1j jS 1 2

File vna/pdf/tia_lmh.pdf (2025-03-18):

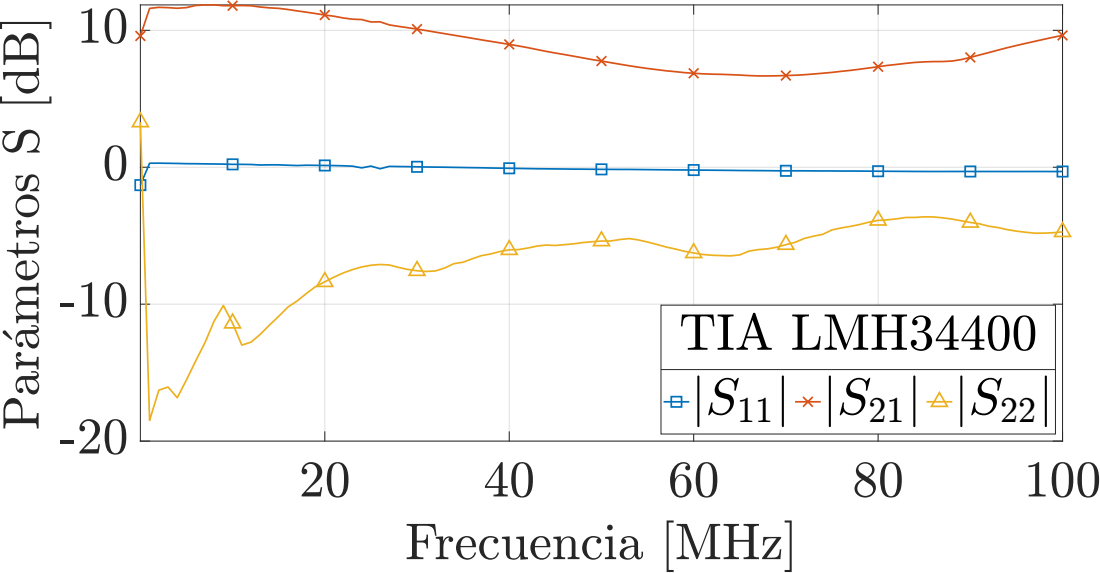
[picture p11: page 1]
0 Par4ametros S [dB] jS; 2j TIA LMH34400

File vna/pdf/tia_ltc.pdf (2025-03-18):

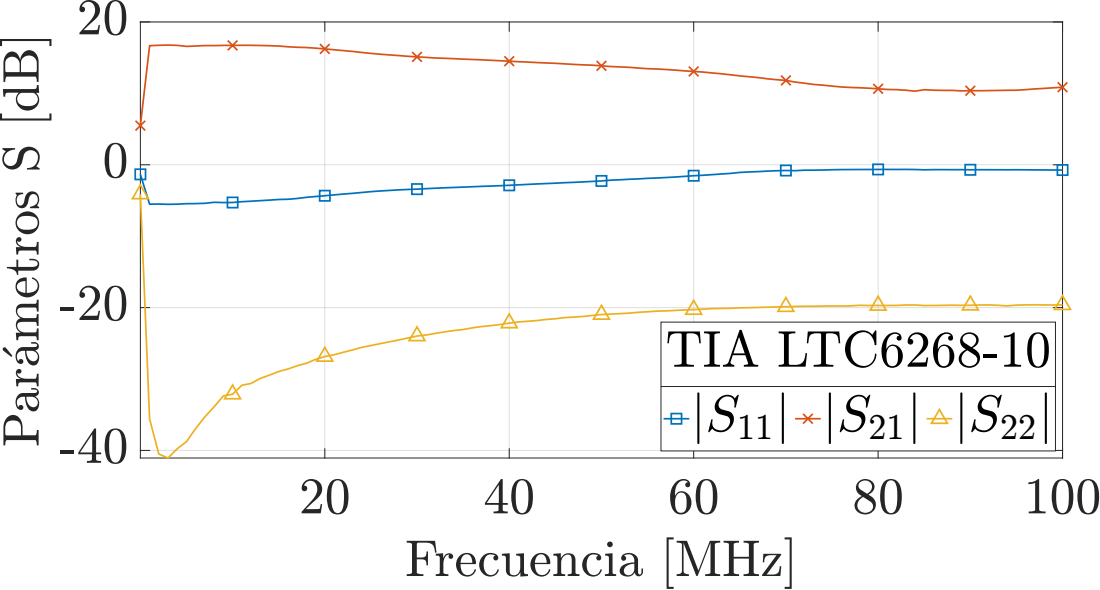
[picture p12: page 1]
0 Par4ametros S [dB] jS; 2j TIA LTC6268-10

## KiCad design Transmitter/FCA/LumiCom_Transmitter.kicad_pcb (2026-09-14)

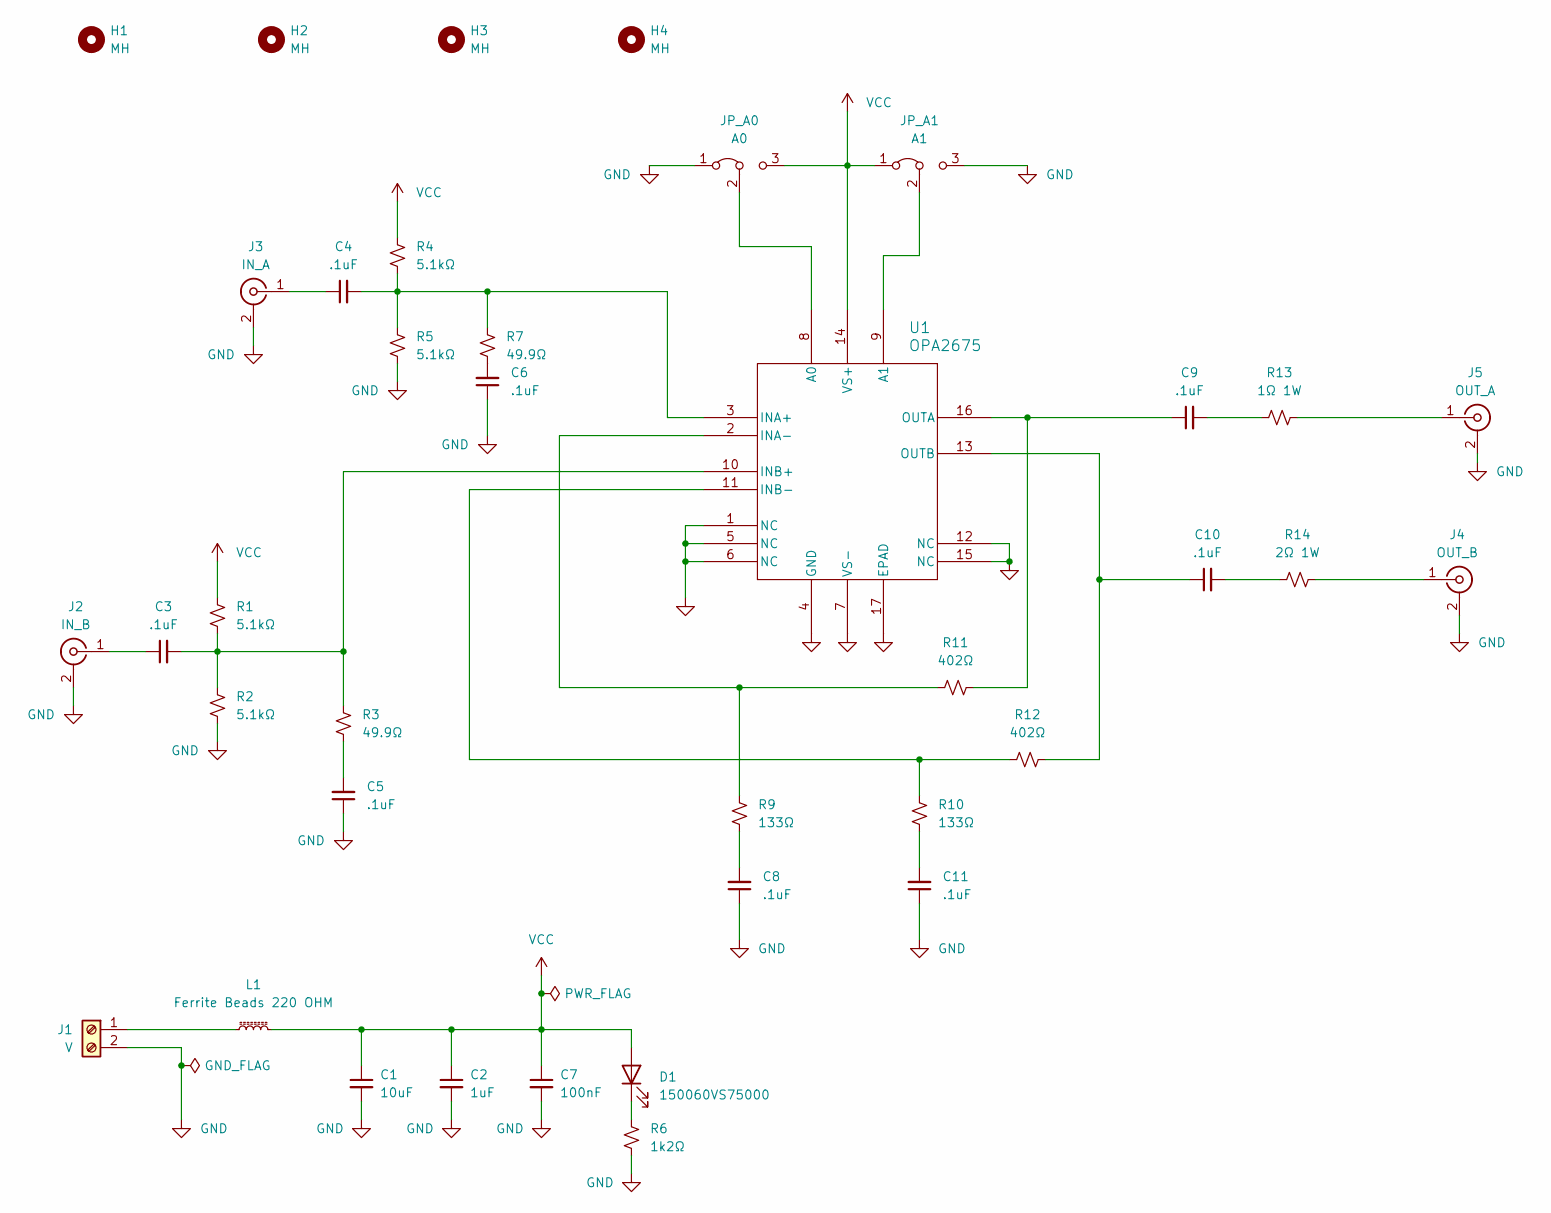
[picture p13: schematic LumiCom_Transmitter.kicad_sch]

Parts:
C1: 10uF; C_0603_1608Metric_Pad1.08x0.95mm_HandSolder; Manufacturer Part Number GRM188Z71A106MA73D; Mouser Part Number 81-GRM188Z71A106MA3D
C2: 1uF; C_0603_1608Metric_Pad1.08x0.95mm_HandSolder; Manufacturer Part Number CL10B105KP8NNNC; Mouser Part Number 187-CL10B105KP8NNNC
C3, C4, C5, C6, C8, C9, C10, C11: .1uF; C_0402_1005Metric_Pad0.74x0.62mm_HandSolder; Manufacturer Part Number 530L104KT16; Mouser Part Number 581-530L104KT16
C7: 100nF; C_0603_1608Metric_Pad1.08x0.95mm_HandSolder; Manufacturer Part Number CL10B104KO8NFNC; Mouser Part Number 187-CL10B104KO8NFNC
D1: 150060VS75000; LEDC1608X80N; Manufacturer Part Number 150060VS75000; Mouser Part Number 710-150060VS75000
H1, H2, H3, H4: MH; MountingHole_3.2mm_M3_ISO7380
J1: V; TerminalBlock_Phoenix_MKDS-1,5-2_1x02_P5.00mm_Horizontal
J2: IN_B; SMA_Samtec_SMA-J-P-X-ST-EM1_EdgeMount
J3: IN_A; SMA_Samtec_SMA-J-P-X-ST-EM1_EdgeMount
J4: OUT_B; SMA_Samtec_SMA-J-P-X-ST-EM1_EdgeMount
J5: OUT_A; SMA_Samtec_SMA-J-P-X-ST-EM1_EdgeMount
JP_A0: A0; PinHeader_1x03_P2.54mm_Vertical
JP_A1: A1; PinHeader_1x03_P2.54mm_Vertical
L1: Ferrite Beads 220 OHM; L_0603_1608Metric_Pad1.05x0.95mm_HandSolder; Manufacturer Part Number BLM18KG221SN1D; Mouser Part Number 81-BLM18KG221SN1D
R1, R2, R4, R5: 5.1kΩ; R_0603_1608Metric; Manufacturer Part Number CRCW06035K10FKEA; Mouser Part Number 71-CRCW0603-5.1K-E3
R3, R7: 49.9Ω; R_0603_1608Metric; Manufacturer Part Number MCT06030C4999FP500; Mouser Part Number 594-MCT06030C4999FP5
R6: 1k2Ω; R_0603_1608Metric_Pad0.98x0.95mm_HandSolder; Manufacturer Part Number CRCW06031K20FKEA; Mouser Part Number 71-CRCW0603-1.2K-E3
R9, R10: 133Ω; R_0402_1005Metric_Pad0.72x0.64mm_HandSolder; Manufacturer Part Number CRT0402-FZ-1330GLF; Mouser Part Number 652-CRT0402FZ1330GLF
R11, R12: 402Ω; R_0402_1005Metric_Pad0.72x0.64mm_HandSolder; Manufacturer Part Number CRT0402-FZ-4020GLF; Mouser Part Number 652-CRT0402FZ4020GLF
R13: 1Ω 1W; R_1206_3216Metric_Pad1.30x1.75mm_HandSolder; Manufacturer Part Number RNCL1206FT1R00; Mouser Part Number 708-RNCL1206FT1R00
R14: 2Ω 1W; R_1206_3216Metric_Pad1.30x1.75mm_HandSolder; Manufacturer Part Number RNCL1206FT2R00; Mouser Part Number 708-RNCL1206FT2R00
U1: OPA2675; Texas_OPA2675; Manufacturer Part Number OPA2675RGVR; Mouser Part Number 595-OPA2675RGVR

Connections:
GND: C1.2, C2.2, C5.1, C6.1, C7.2, C8.1, C11.1, J1.2, J2.2 (Ext), J3.2 (Ext), J4.2 (Ext), J5.2 (Ext), JP_A0.1 (A), JP_A1.3 (B), R2.2, R5.2, R6.2, U1.1 (NC), U1.4 (GND), U1.5 (NC), U1.6 (NC), U1.7 (VS-), U1.12 (NC), U1.15 (NC), U1.17 (EPAD)
unnamed: C5.2, R3.2
unnamed: C6.2, R7.2
unnamed: C8.2, R9.1
unnamed: C9.2, R13.1
unnamed: C10.2, R14.1
unnamed: C11.2, R10.1
unnamed: D1.1 (K), R6.1
unnamed: J1.1, L1.1
unnamed: C3.1, J2.1 (In)
unnamed: C4.1, J3.1 (In)
unnamed: J4.1 (In), R14.2
unnamed: J5.1 (In), R13.2
unnamed: JP_A0.2 (C), U1.8 (A0)
unnamed: JP_A1.2 (C), U1.9 (A1)
unnamed: C4.2, R4.2, R5.1, R7.1, U1.3 (INA+)
unnamed: R9.2, R11.1, U1.2 (INA-)
unnamed: C3.2, R1.2, R2.1, R3.1, U1.10 (INB+)
unnamed: R10.2, R12.1, U1.11 (INB-)
unnamed: C9.1, R11.2, U1.16 (OUTA)
unnamed: C10.1, R12.2, U1.13 (OUTB)
VCC: C1.1, C2.1, C7.1, D1.2 (A), JP_A0.3 (B), JP_A1.1 (A), L1.2, R1.1, R4.1, U1.14 (VS+)

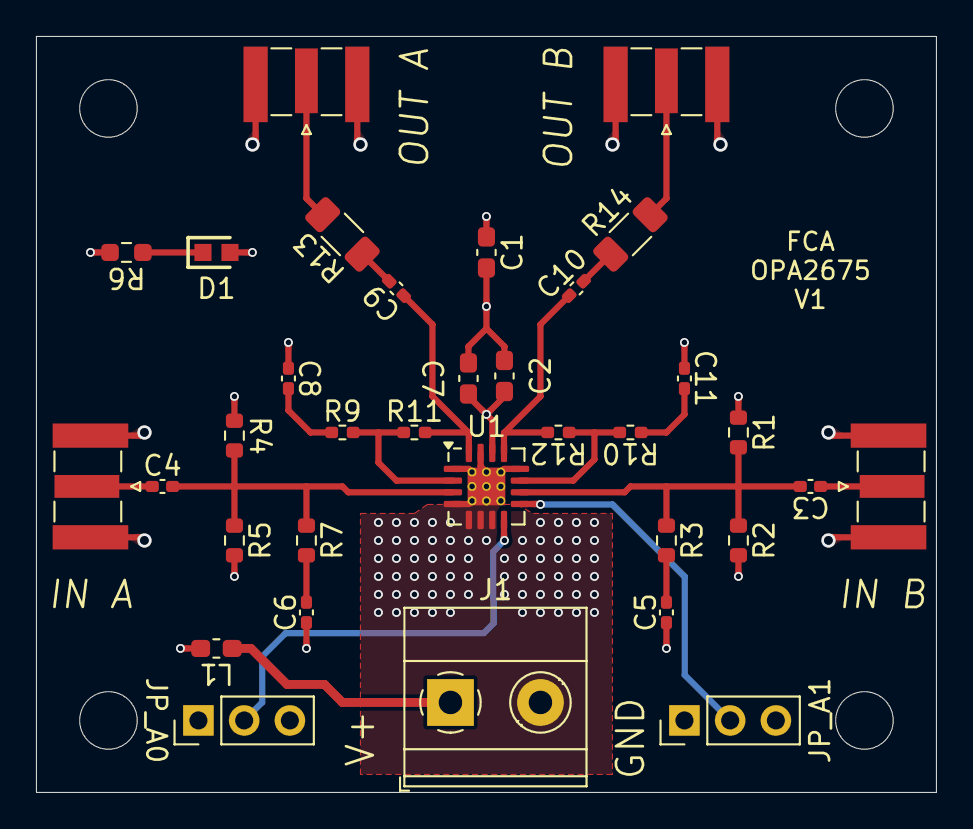
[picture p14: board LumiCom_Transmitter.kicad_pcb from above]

Board: 4 copper layers, 50.0 x 42.0 mm, 38 parts (0 on the bottom side), 22 nets.

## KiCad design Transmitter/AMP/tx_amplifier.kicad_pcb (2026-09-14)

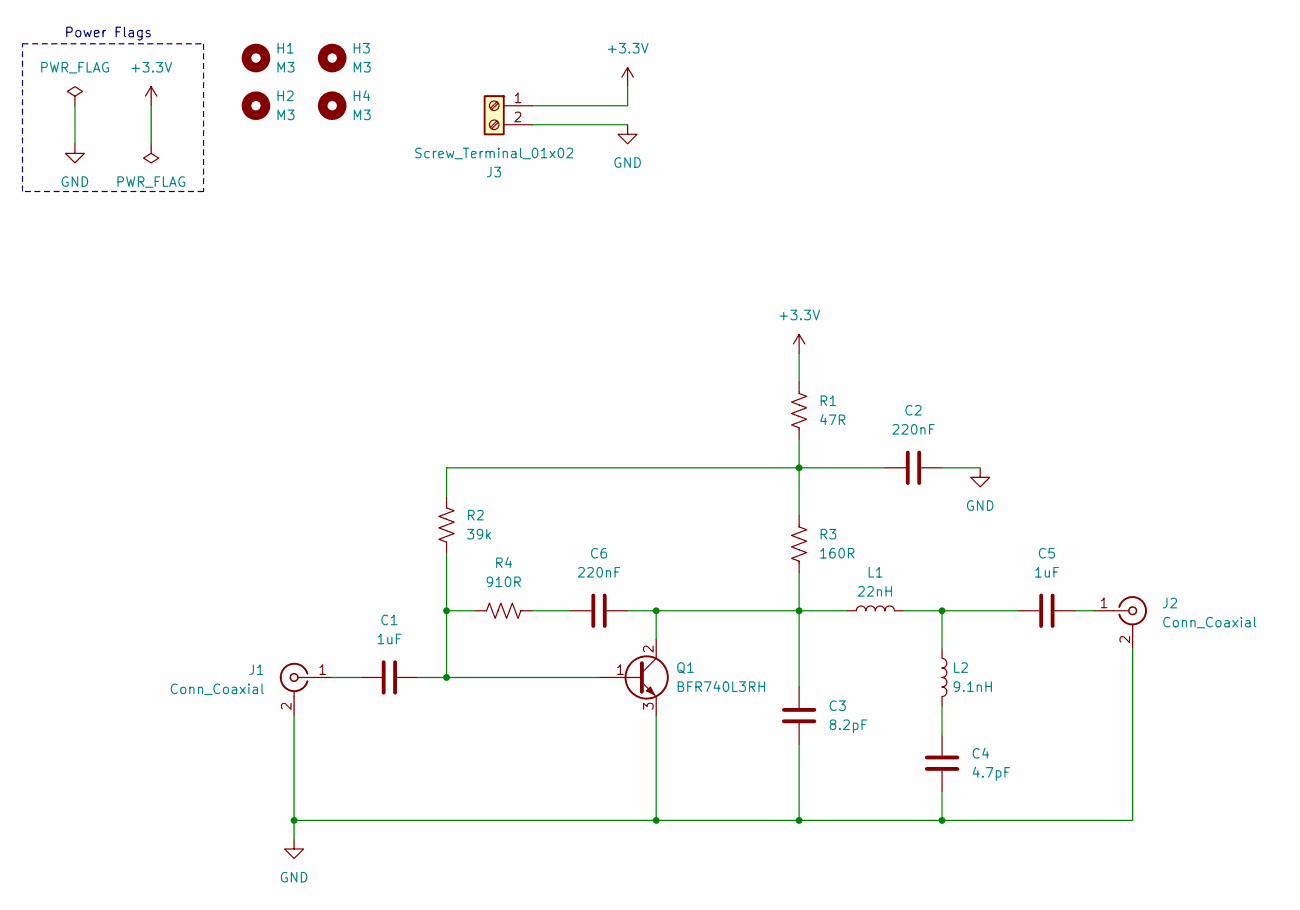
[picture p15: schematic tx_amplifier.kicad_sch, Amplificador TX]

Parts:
C1, C5: 1uF; C_0603_1608Metric_Pad1.08x0.95mm_HandSolder; Manufacturer P/N SH18B105K160CT; Mouser P/N 791-SH18B105K160CT
C2, C6: 220nF; C_0603_1608Metric_Pad1.08x0.95mm_HandSolder; Manufacturer P/N 0603B224K250CT; Mouser P/N 791-0603B224K250CT
C3: 8.2pF; C_0603_1608Metric_Pad1.08x0.95mm_HandSolder; Manufacturer P/N 0603N8R2C500CT; Mouser P/N 791-0603N8R2C500CT
C4: 4.7pF; C_0603_1608Metric_Pad1.08x0.95mm_HandSolder; Manufacturer P/N 0603N4R7C500CT; Mouser P/N 791-0603N4R7C500CT
H1, H2, H3, H4: M3; MountingHole_3.2mm_M3_ISO7380; Manufacturer P/N N/A; Mouser P/N N/A
J1, J2: Conn_Coaxial; SMA_Samtec_SMA-J-P-X-ST-EM1_EdgeMount; Manufacturer P/N SMA-KE1.2mm; Mouser P/N N/A
J3: Screw_Terminal_01x02; TerminalBlock_bornier-2_P5.08mm; Manufacturer P/N VI0221550000G; Mouser P/N 649-220316-H021B01LF
L1: 22nH; L_0603_1608Metric_Pad1.05x0.95mm_HandSolder; Manufacturer P/N 7847806220; Mouser P/N 710-7847806220
L2: 9.1nH; L_0603_1608Metric_Pad1.05x0.95mm_HandSolder; Manufacturer P/N LQW18AN9N1C00D; Mouser P/N 81-LQW18AN9N1C00D
Q1: BFR740L3RH; TSLP-3-9; Manufacturer P/N BFR740L3RHE6327XTSA1; Mouser P/N 726-BFR740L3RHE6327X
R1: 47R; R_1206_3216Metric_Pad1.30x1.75mm_HandSolder; Manufacturer P/N RC1206FR-0747RL; Mouser P/N 603-RC1206FR-0747RL
R2: 39k; R_0603_1608Metric_Pad0.98x0.95mm_HandSolder; Manufacturer P/N RT0603FRE0739KL; Mouser P/N 603-RT0603FRE0739KL
R3: 160R; R_1206_3216Metric_Pad1.30x1.75mm_HandSolder; Manufacturer P/N RC1206FR-07160RL; Mouser P/N 603-RC1206FR-07160RL
R4: 910R; R_0603_1608Metric_Pad0.98x0.95mm_HandSolder; Manufacturer P/N RT0603FRE07910RL; Mouser P/N 603-RT0603FRE07910RL

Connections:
+3.3V: J3.1, R1.2
GND: C2.2, C3.1, C4.1, J1.2 (Ext), J2.2 (Ext), J3.2, Q1.3 (E)
unnamed: C2.1, R1.1, R2.2, R3.2
unnamed: C4.2, L2.2
unnamed: C5.1, L1.2, L2.1
unnamed: C6.1, R4.1
unnamed: C1.1, J1.1 (In)
unnamed: C5.2, J2.1 (In)
unnamed: C1.2, Q1.1 (B), R2.1, R4.2
unnamed: C3.2, C6.2, L1.1, Q1.2 (C), R3.1

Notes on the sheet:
Power Flags

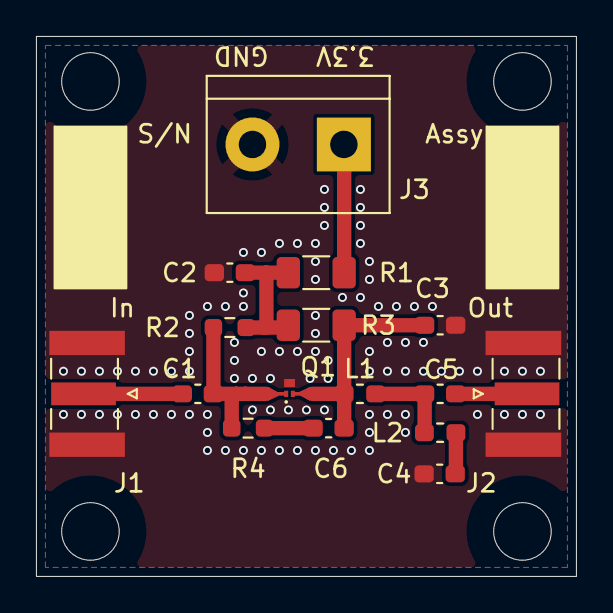
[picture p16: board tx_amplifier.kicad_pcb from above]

Board: 2 copper layers, 30.0 x 30.0 mm, 20 parts (0 on the bottom side), 10 nets.

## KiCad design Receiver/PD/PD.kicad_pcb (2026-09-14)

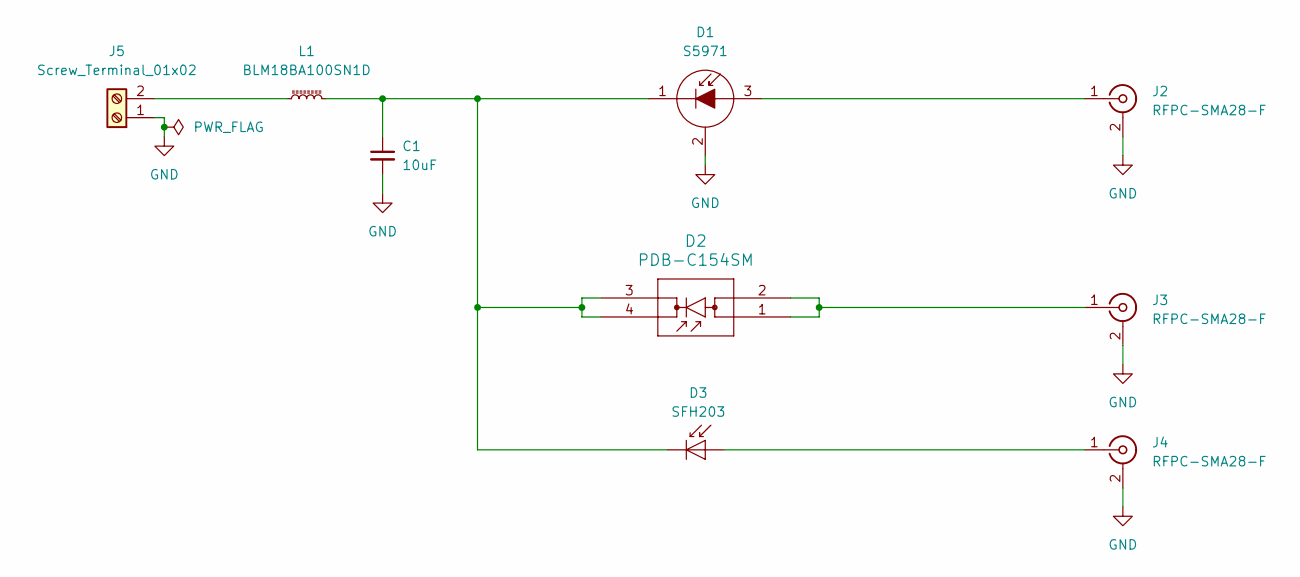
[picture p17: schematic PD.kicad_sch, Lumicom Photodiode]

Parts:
C1: 10uF; C_0603_1608Metric_Pad1.08x0.95mm_HandSolder
D1: S5971; TO-18-3; Mfr P/N S5971
D2: PDB-C154SM; PDB-C154SM_ADP; Mfr P/N PDB-C154SM; Mouser P/N 846-PDB-C154SM
D3: SFH203; LED_D5.0mm_IRGrey; Mfr P/N SFH 203 P; Mouser P/N 720-SFH203P
J2, J3, J4: RFPC-SMA28-F
J5: Screw_Terminal_01x02; TerminalBlock_bornier-2_P5.08mm
L1: BLM18BA100SN1D; L_0603_1608Metric_Pad1.05x0.95mm_HandSolder

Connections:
GND: C1.2, D1.2 (C), J2.2 (Ext), J3.2 (Ext), J4.2 (Ext), J5.1
unnamed: D1.3 (A), J2.1 (In)
unnamed: C1.1, D1.1 (K), D2.3 (CATHODE), D2.4 (CATHODE), D3.1 (K), L1.2
unnamed: D3.2 (A), J4.1 (In)
unnamed: D2.1 (ANODE), D2.2 (ANODE), J3.1 (In)
unnamed: J5.2, L1.1

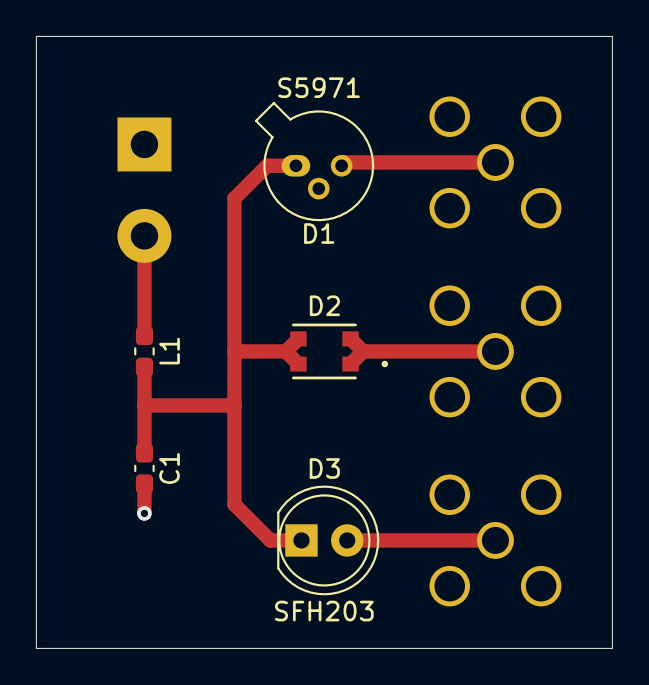
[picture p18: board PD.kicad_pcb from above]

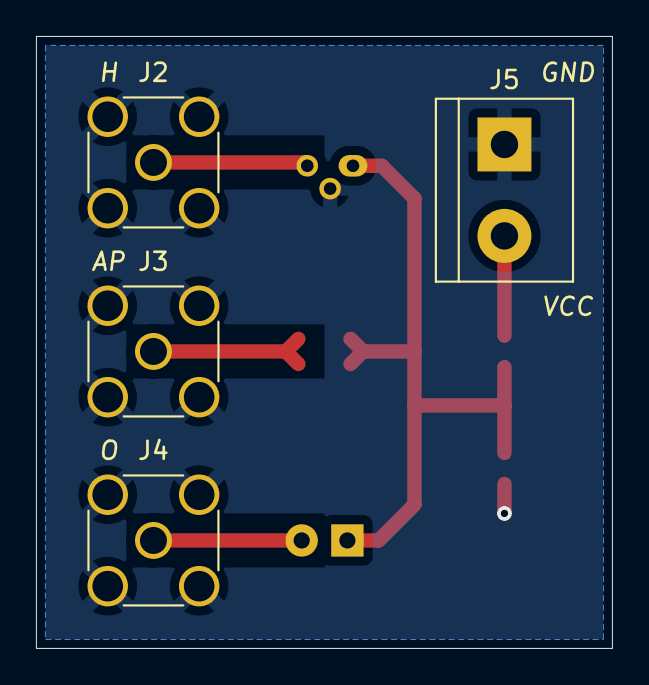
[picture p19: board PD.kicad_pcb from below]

Board: 2 copper layers, 32.0 x 34.0 mm, 9 parts (4 on the bottom side), 6 nets.

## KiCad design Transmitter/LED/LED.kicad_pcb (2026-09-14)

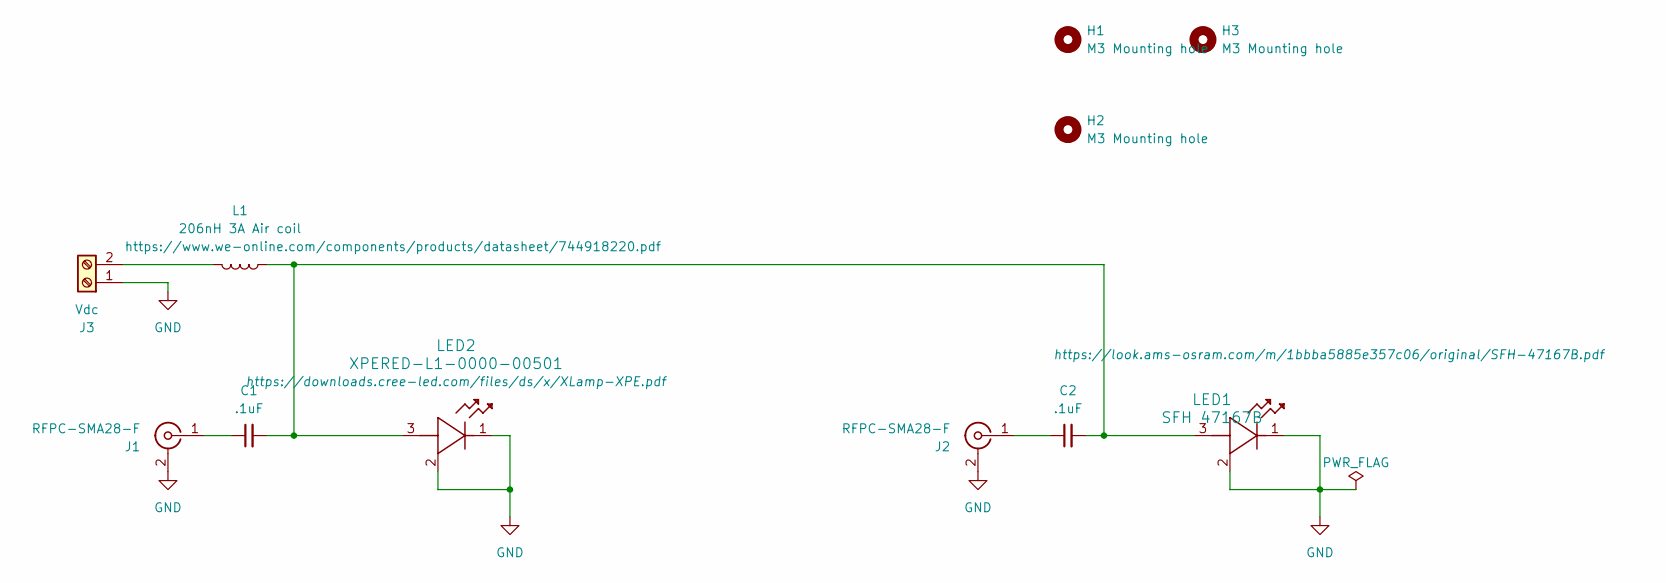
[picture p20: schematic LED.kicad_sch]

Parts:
C1, C2: .1uF; C_0402_1005Metric_Pad0.74x0.62mm_HandSolder; Manufacturer Part Number 530L104KT16; Mouser Part Number 581-530L104KT16
H1, H2, H3: M3 Mounting hole; MountingHole_3.2mm_M3_DIN965
J1, J2: RFPC-SMA28-F; Manufacturer Part Number RFPC-SMA28-F; Mouser Part Number 640-RFPCSMA28F
J3: Vdc; TerminalBlock_Phoenix_MKDS-1,5-2_1x02_P5.00mm_Horizontal
L1: 206nH 3A Air coil; L_Wurth_WE-CAIR-5910; Manufacturer Part Number 744918220; Mouser Part Number 710-744918220
LED1: SFH 47167B
LED2: XPERED-L1-0000-00501; LED_CREE_XPLx

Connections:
GND: J1.2 (Ext), J2.2 (Ext), J3.1, LED1.1 (cathode), LED1.2 (thermal), LED2.1 (cathode), LED2.2 (thermal)
unnamed: C1.1, J1.1 (In)
unnamed: C2.1, J2.1 (In)
unnamed: J3.2, L1.2
unnamed: C1.2, C2.2, L1.1, LED1.3 (anode), LED2.3 (anode)

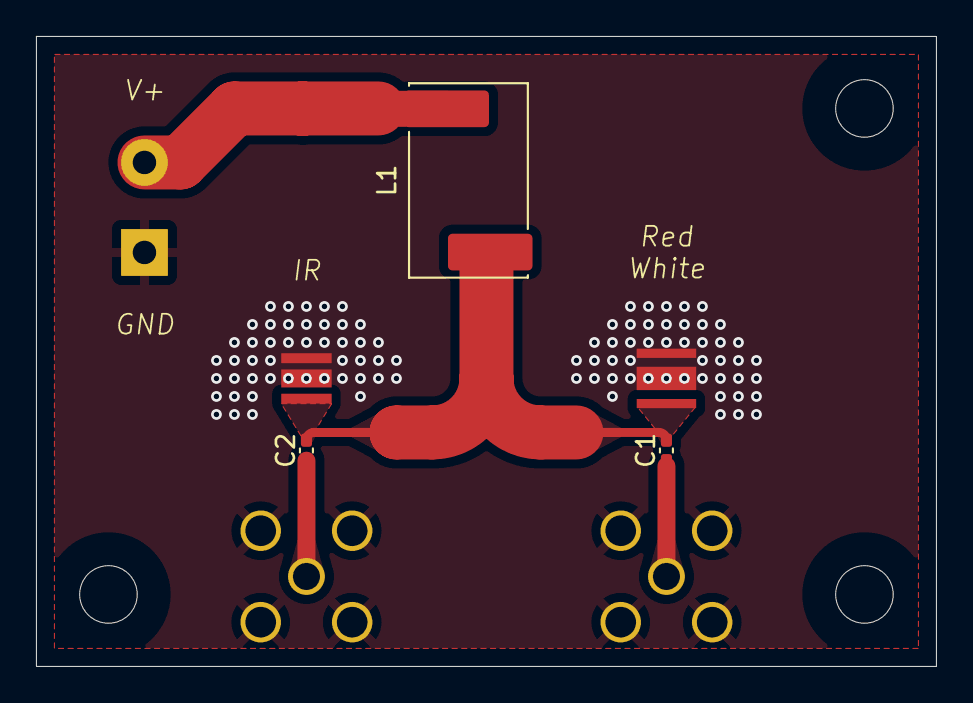
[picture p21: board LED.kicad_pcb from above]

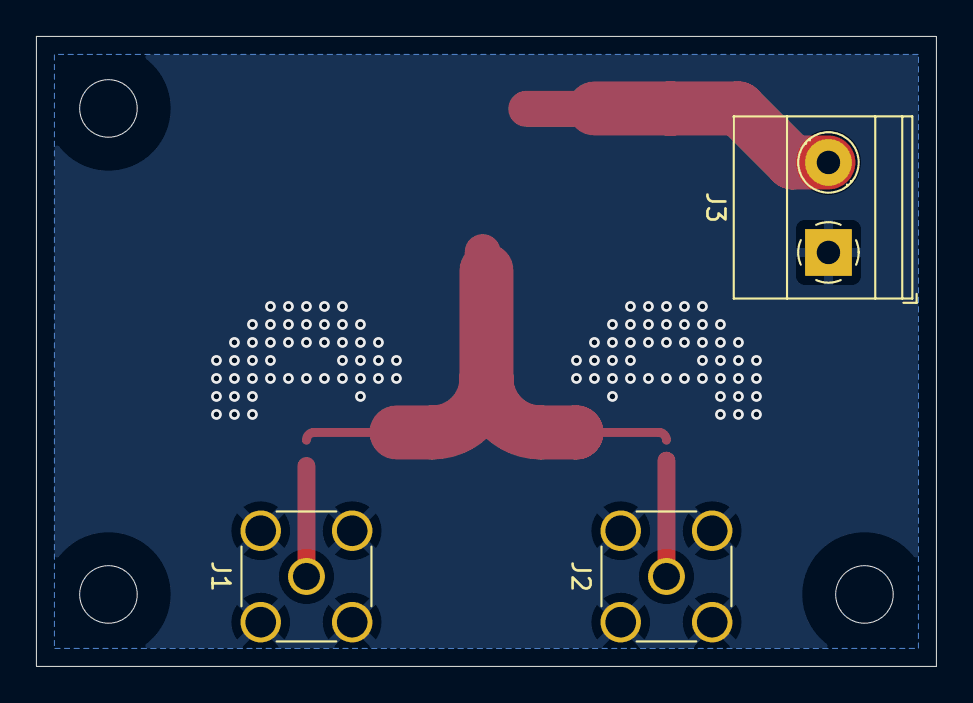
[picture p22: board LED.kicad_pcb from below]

Board: 2 copper layers, 50.0 x 35.0 mm, 11 parts (3 on the bottom side), 5 nets.

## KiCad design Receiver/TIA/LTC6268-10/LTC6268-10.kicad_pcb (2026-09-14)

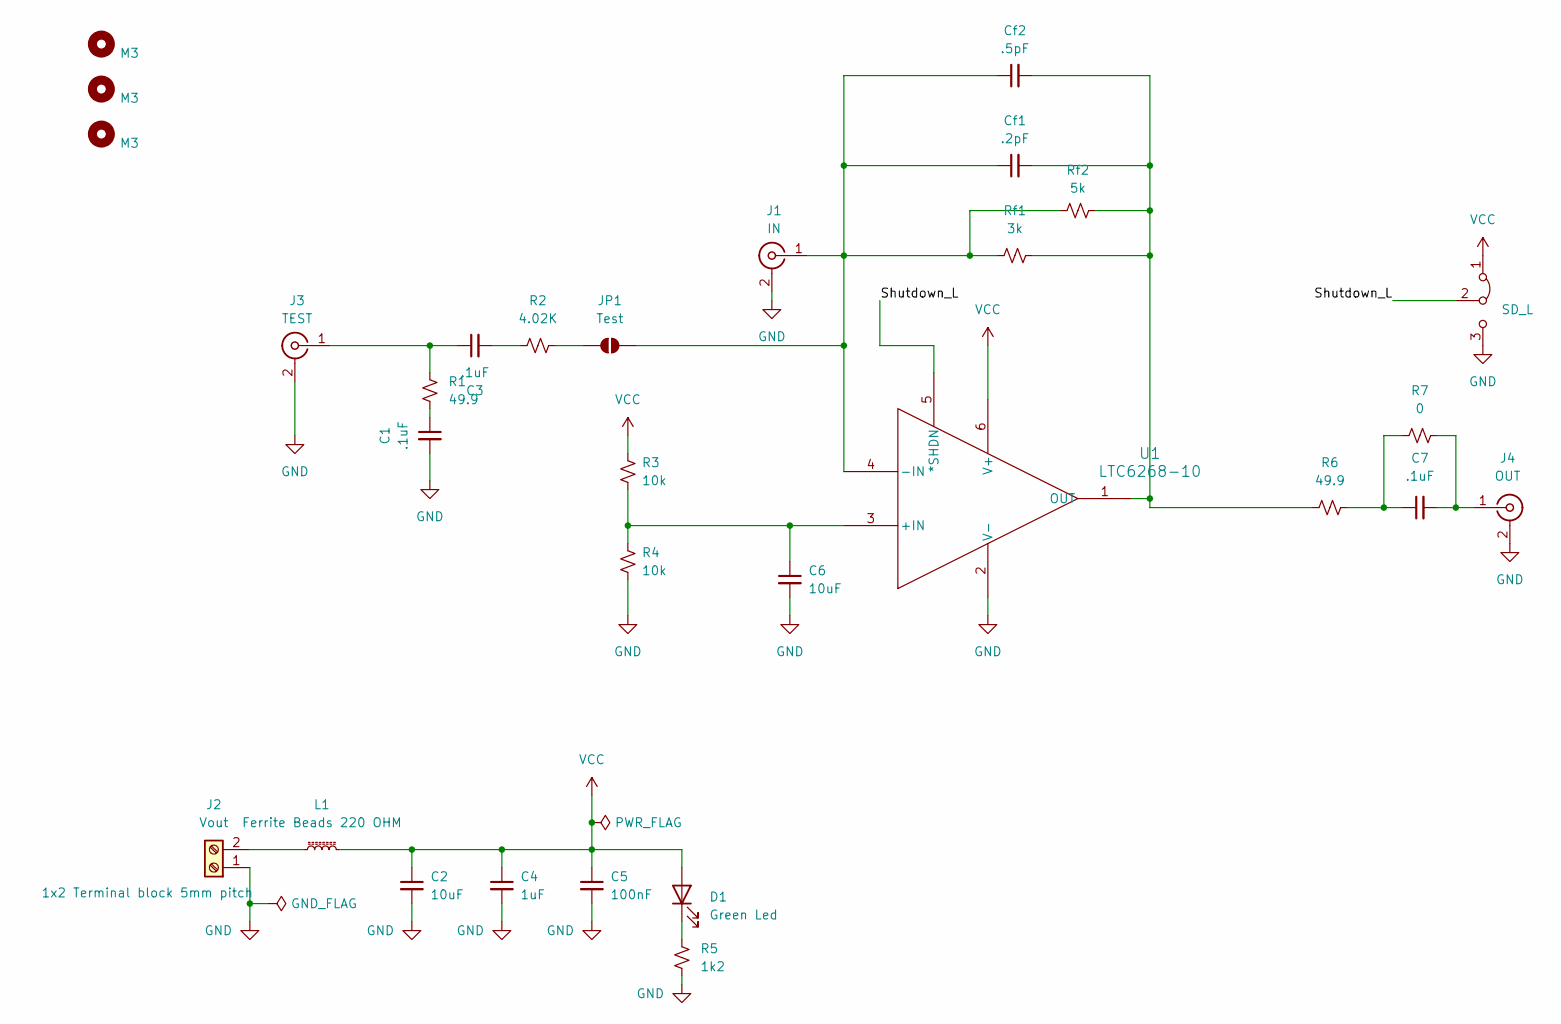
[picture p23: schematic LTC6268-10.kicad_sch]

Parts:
C1, C3, C7: .1uF; C_0402_1005Metric_Pad0.74x0.62mm_HandSolder; Manufacturer Part Number 530L104KT16; Mouser Part Number 581-530L104KT16
C2, C6: 10uF; C_0603_1608Metric_Pad1.08x0.95mm_HandSolder; Manufacturer Part Number GRM188Z71A106MA73D; Mouser Part Number 81-GRM188Z71A106MA3D
C4: 1uF; C_0603_1608Metric_Pad1.08x0.95mm_HandSolder; Manufacturer Part Number CL10B105KP8NNNC; Mouser Part Number 187-CL10B105KP8NNNC
C5: 100nF; C_0603_1608Metric_Pad1.08x0.95mm_HandSolder; Manufacturer Part Number CL10B104KO8NFNC; Mouser Part Number 187-CL10B104KO8NFNC
Cf1: .2pF; C_0402_1005Metric; Manufacturer Part Number 04023J0R2ZBSTR; Mouser Part Number 581-04023J0R2ZBSTR
Cf2: .5pF; C_0402_1005Metric; Manufacturer Part Number 04023J0R5BBSTR; Mouser Part Number 581-04023J0R5BBSTR
D1: Green Led; LED_0603_1608Metric; Manufacturer Part Number 150060VS75000; Mouser Part Number 710-150060VS75000
H1, H2, H3: M3; MountingHole_3.2mm_M3_DIN965
J1: IN; SMA_Samtec_SMA-J-P-X-ST-EM1_EdgeMount
J2: Vout; TerminalBlock_Phoenix_MKDS-1,5-2_1x02_P5.00mm_Horizontal
J3: TEST; SMA_Samtec_SMA-J-P-X-ST-EM1_EdgeMount
J4: OUT; SMA_Samtec_SMA-J-P-X-ST-EM1_EdgeMount
JP1: Test; R_0603_1608Metric_Pad0.98x0.95mm_HandSolder; Manufacturer Part Number MCT0603MZ0000ZP500; Mouser Part Number 594-MCT0603MZ0000ZP5
L1: Ferrite Beads 220 OHM; L_0603_1608Metric_Pad1.05x0.95mm_HandSolder; Manufacturer Part Number BLM18KG221SN1D; Mouser Part Number 81-BLM18KG221SN1D
R1, R6: 49.9; R_0603_1608Metric_Pad0.98x0.95mm_HandSolder; Manufacturer Part Number MCT06030C4999FP500; Mouser Part Number 594-MCT06030C4999FP5
R2: 4.02K; R_0603_1608Metric_Pad0.98x0.95mm_HandSolder; Manufacturer Part Number MCT06030C4021FP500; Mouser Part Number 594-MCT06030C4021FP5
R3, R4: 10k; R_0603_1608Metric_Pad0.98x0.95mm_HandSolder; Manufacturer Part Number CRCW060310K0FKEI; Mouser Part Number 71-CRCW060310K0FKEI
R5: 1k2; R_0603_1608Metric_Pad0.98x0.95mm_HandSolder; Manufacturer Part Number CRCW06031K20FKEA; Mouser Part Number 71-CRCW0603-1.2K-E3
R7: 0; R_0603_1608Metric_Pad0.98x0.95mm_HandSolder; Manufacturer Part Number MCT0603MZ0000ZP500; Mouser Part Number 594-MCT0603MZ0000ZP5
Rf1: 3k; R_0402_1005Metric; Manufacturer Part Number MCS04020D3001BE000; Mouser Part Number 594-MCS04020D3001BE0
Rf2: 5k; R_0402_1005Metric; Manufacturer Part Number MCS04020C4991FE000; Mouser Part Number 594-MCS04020C4991FE0
SD_L1: SD_L; PinHeader_1x03_P2.54mm_Vertical
U1: LTC6268-10; TSOT-23_S6_LIT; Manufacturer Part Number LTC6268IS6-10#TRMPBF; Mouser Part Number 584-C6268IS6-10TMPF

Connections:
/Shutdown_L: SD_L1.2 (C), U1.5 (*SHDN)
GND: C1.2, C2.2, C4.2, C5.2, C6.2, J1.2 (Ext), J2.1, J3.2 (Ext), J4.2 (Ext), R4.2, R5.2, SD_L1.3 (B), U1.2 (V-)
unnamed: C1.1, R1.2
unnamed: C3.2, R2.1
unnamed: C7.1, R6.2, R7.1
unnamed: D1.1 (K), R5.1
unnamed: Cf1.1, Cf2.1, J1.1 (In), JP1.2 (B), Rf1.1, Rf2.1, U1.4 (-IN)
unnamed: J2.2, L1.1
unnamed: C3.1, J3.1 (In), R1.1
unnamed: C7.2, J4.1 (In), R7.2
unnamed: JP1.1 (A), R2.2
unnamed: C6.1, R3.2, R4.1, U1.3 (+IN)
unnamed: Cf1.2, Cf2.2, R6.1, Rf1.2, Rf2.2, U1.1 (OUT)
VCC: C2.1, C4.1, C5.1, D1.2 (A), L1.2, R3.1, SD_L1.1 (A), U1.6 (V+)

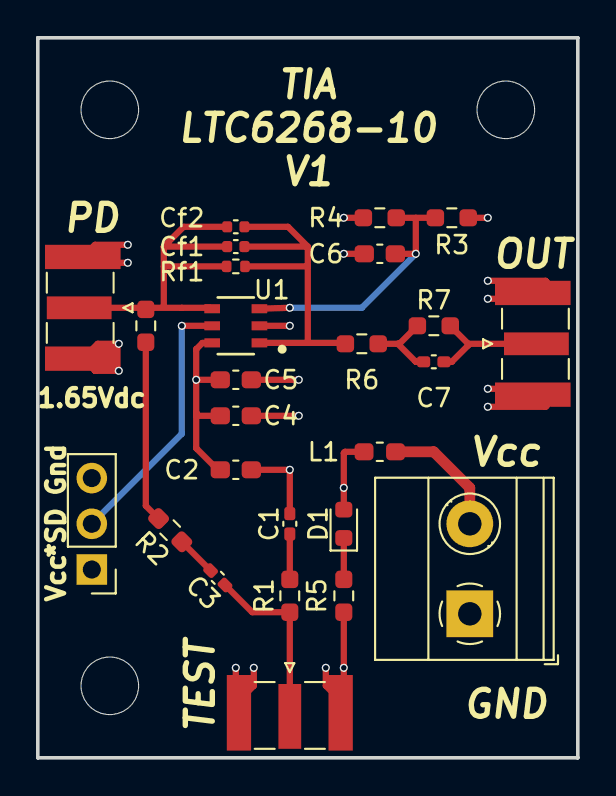
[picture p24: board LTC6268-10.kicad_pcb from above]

Board: 4 copper layers, 30.0 x 40.0 mm, 29 parts (0 on the bottom side), 14 nets.

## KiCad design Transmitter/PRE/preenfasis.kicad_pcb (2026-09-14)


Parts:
C1, C2, C3, C4: 62pF; C_0603_1608Metric_Pad1.08x0.95mm_HandSolder; Manufacturer P/N CC0603JRNPO9BN620; Mouser P/N 603-CC603JRNPO9BN620
H1, H2, H3, H4: M3; MountingHole_3.2mm_M3_ISO7380; Manufacturer P/N N/A; Mouser P/N N/A
J1, J2, J3, J4: SMA H; SMA_Samtec_SMA-J-P-X-ST-EM1_EdgeMount; Manufacturer P/N Electrocomponentes; Mouser P/N N/A
L1, L2, L3, L4: 150nH; L_0603_1608Metric_Pad1.05x0.95mm_HandSolder; Manufacturer P/N MLJ1608WR15JT000; Mouser P/N 810-MLJ1608WR15JT000
R1, R5: 825R; R_0603_1608Metric_Pad0.98x0.95mm_HandSolder; Manufacturer P/N RT0603FRE07825RL; Mouser P/N 603-RT0603FRE07825RL
R2, R6: 3R; R_0603_1608Metric_Pad0.98x0.95mm_HandSolder; Manufacturer P/N RT0603FRE073RL; Mouser P/N 603-RT0603FRE073RL
R3, R4, R7, R8: 49.9R; R_0603_1608Metric_Pad0.98x0.95mm_HandSolder; Manufacturer P/N RT0603FRE0749R9L; Mouser P/N 603-RT0603FRE0749R9L

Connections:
unnamed: C1.2, L1.1
unnamed: C2.2, L2.1, R2.2
unnamed: C3.2, L3.1
unnamed: C4.2, L4.1, R6.2
unnamed: C2.1, J1.2 (Ext), J2.2 (Ext), L2.2
unnamed: C1.1, J1.1 (In), R1.1, R3.1
unnamed: J2.1 (In), L1.2, R1.2, R4.2
unnamed: C4.1, J3.2 (Ext), J4.2 (Ext), L4.2
unnamed: C3.1, J3.1 (In), R5.1, R7.1
unnamed: J4.1 (In), L3.2, R5.2, R8.2
unnamed: R2.1, R3.2, R4.1
unnamed: R6.1, R7.2, R8.1

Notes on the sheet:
Mounting Holes


Board: 2 copper layers, 25.0 x 40.0 mm, 24 parts (0 on the bottom side), 12 nets.

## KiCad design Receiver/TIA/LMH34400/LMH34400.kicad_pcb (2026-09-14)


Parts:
C1, C2, C6: .1uF; C_0402_1005Metric_Pad0.74x0.62mm_HandSolder; Manufacturer Part Number 530L104KT16; Mouser Part Number 581-530L104KT16
C3: 10uF; C_0603_1608Metric_Pad1.08x0.95mm_HandSolder; Manufacturer Part Number GRM188Z71A106MA73D; Mouser Part Number 81-GRM188Z71A106MA3D
C4: 1uF; C_0603_1608Metric_Pad1.08x0.95mm_HandSolder; Manufacturer Part Number CL10B105KP8NNNC; Mouser Part Number 187-CL10B105KP8NNNC
C5: 100nF; C_0603_1608Metric_Pad1.08x0.95mm_HandSolder; Manufacturer Part Number CL10B104KO8NFNC; Mouser Part Number 187-CL10B104KO8NFNC
D1: Green led; LED_0603_1608Metric; Manufacturer Part Number 150060VS75000; Mouser Part Number 710-150060VS75000
H1, H2, H3: M3; MountingHole_3.2mm_M3_DIN965
J1: TEST; SMA_Samtec_SMA-J-P-X-ST-EM1_EdgeMount
J2: PD IN; SMA_Samtec_SMA-J-P-X-ST-EM1_EdgeMount
J3: Vout; TerminalBlock_Phoenix_MKDS-1,5-2_1x02_P5.00mm_Horizontal
J4: N_EN; PinHeader_1x03_P2.54mm_Vertical
J5: N_ALC; PinHeader_1x03_P2.54mm_Vertical
J6: OUT; SMA_Samtec_SMA-J-P-X-ST-EM1_EdgeMount
JP1: Test; R_0603_1608Metric_Pad0.98x0.95mm_HandSolder; Manufacturer Part Number MCT0603MZ0000ZP500; Mouser Part Number 594-MCT0603MZ0000ZP5; not fitted
L1: Ferrite Beads 220 OHM; L_0603_1608Metric_Pad1.05x0.95mm_HandSolder; Manufacturer Part Number BLM18KG221SN1D; Mouser Part Number 81-BLM18KG221SN1D
R1, R4: 49.9; R_0603_1608Metric_Pad0.98x0.95mm_HandSolder; Manufacturer Part Number MCT06030C4999FP500; Mouser Part Number 594-MCT06030C4999FP5
R2: 4.02K; R_0603_1608Metric_Pad0.98x0.95mm_HandSolder; Manufacturer Part Number MCT06030C4021FP500; Mouser Part Number 594-MCT06030C4021FP5
R3: 1k2; R_0603_1608Metric_Pad0.98x0.95mm_HandSolder; Manufacturer Part Number CRCW06031K20FKEA; Mouser Part Number 71-CRCW0603-1.2K-E3
R5: 0; R_0603_1608Metric_Pad0.98x0.95mm_HandSolder; Manufacturer Part Number MCT0603MZ0000ZP500; Mouser Part Number 594-MCT0603MZ0000ZP5
U1: LMH34400; SOT5X3-6_DRL_TEX; Manufacturer Part Number LMH34400IDRLR; Mouser Part Number 595-LMH34400IDRLR

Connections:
GND: C1.2, C3.2, C4.2, C5.2, J1.2 (Ext), J2.2 (Ext), J3.1, J4.3, J5.3, J6.2 (Ext), R3.2, U1.5 (GND)
unnamed: C1.1, R1.2
unnamed: C2.2, R2.1
unnamed: C6.1, R4.2, R5.1
unnamed: D1.1 (K), R3.1
unnamed: C2.1, J1.1 (In), R1.1
unnamed: J2.1 (In), JP1.2 (B), U1.1 (IN)
unnamed: J3.2, L1.1
unnamed: J4.2, U1.3 (*EN)
unnamed: J5.2, U1.6 (*IDC_EN)
unnamed: C6.2, J6.1 (In), R5.2
unnamed: JP1.1 (A), R2.2
unnamed: R4.1, U1.4 (OUT)
VCC: C3.1, C4.1, C5.1, D1.2 (A), J4.1, J5.1, L1.2, U1.2 (VDD)


Board: 4 copper layers, 34.0 x 40.0 mm, 24 parts (0 on the bottom side), 14 nets.

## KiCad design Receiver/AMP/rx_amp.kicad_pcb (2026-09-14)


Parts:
C1, C2, C3: .1uF; C_0402_1005Metric_Pad0.74x0.62mm_HandSolder; Mouser Part Number 581-530L104KT16
H1, H3: M3 mounting hole; MountingHole_3.2mm_M3_DIN965
IC1: BGA616H6327XTSA1; Mouser Part Number 726-BGA616H6327XTSA1
J1: Signal_In; SMA_Samtec_SMA-J-P-X-ST-EM1_EdgeMount
J2: Signal_Out; SMA_Samtec_SMA-J-P-X-ST-EM1_EdgeMount
J3: Screw_Terminal_01x02; TerminalBlock_RND_205-00001_1x02_P5.00mm_Horizontal
L1, L2: 10uHy; L_0603_1608Metric_Pad1.05x0.95mm_HandSolder; Mouser Part Number 81-LQM18DZ100M70L
L3: Ferrite Beads 220 OHM; L_0603_1608Metric_Pad1.05x0.95mm_HandSolder; Mouser Part Number 81-BLM18KG221SN1D
R1: 15; L_0603_1608Metric_Pad1.05x0.95mm_HandSolder; Mouser Part Number 710-560112116150

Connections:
GND: C3.2, IC1.2 (GND_1), IC1.4 (GND_2), J1.2 (Ext), J2.2 (Ext), J3.1
unnamed: C3.1, L3.2, R1.1
unnamed: C1.2, IC1.1 (IN)
unnamed: C2.1, IC1.3 (OUT), L2.2
unnamed: C1.1, J1.1 (In)
unnamed: C2.2, J2.1 (In)
unnamed: J3.2, L3.1
unnamed: L1.1, R1.2
unnamed: L1.2, L2.1


Board: 2 copper layers, 30.0 x 30.0 mm, 13 parts (0 on the bottom side), 9 nets.

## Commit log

2026-09-14 Vendor project libraries; clean ERC/DRC on all boards
    - Copy embedded footprints and symbols into each project's local library
    and repoint FPIDs / lib_ids so every project is self-contained
    - Add sym-lib-table for tx_amplifier and preenfasis
    - Sync footprint fields with the schematic (parity) and mark LMH34400 JP1 DNP
    - Remove dangling copper arc and silkscreen overlap in LTC6268-10
    - Fix LED ERC metadata errors
    - All 8 boards: ERC and DRC clean (0 errors, 0 warnings)
    [Amplifier.kicad_sch, Filter.kicad_sch, LED.kicad_pcb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]
2026-09-14 Add project README; move maintenance tools to scripts/; commit review reports
    - README with architecture, board list, workflow and review status
    - Move vendor_footprints, vendor_symbols, sync_schematic_parity and
    summarize_netlists from build/audit to scripts/
    - Version the ERC/DRC reports (docs/review) and the full review (docs/REVISION_PCB.md)
    - Ignore __pycache__/*.pyc
2026-09-14 Unify simulations on ngspice; add TIA noise analysis
    - Add sim/: reproducible ngspice decks (AC, transient, noise) per board,
    plus opamp/TIA macromodels and the Infineon BFR740L3RH model
    - scripts/run_spice.py drives the KiCad libngspice via ctypes (headless)
    - scripts/run_all_sims.sh and summarize_sims.py -> docs/sim/RESULTS.md
    - Add .noise for ltc6268-10 and lmh34400 TIAs
    - New .gitignore for simulation outputs; drop generated LTspice/PSpice
    artifacts (keep .asc/.lib/.s2p/.opj/.olb sources)
    - README/sim docs for the ngspice workflow
2026-09-14 Run vendor macro-models natively in ngspice
    - Add scripts/convert_vendor_model.py to translate the TI PSpice models
    (VSWITCH/ISWITCH -> SW/CSW, PWR -> **, drop noiseless/T_ABS)
    - Generate sim/models/lmh34400.lib and sim/models/opa2675.lib; the LMH34400
    and OPA2675 decks now use the real vendor models (40 kohm integrated gain,
    4.02 closed-loop gain) and their internal noise
    - Set ngbehavior=ltpsa in the runner
    - Add sim/models/bga616.lib (datasheet-based 50 ohm / 19 dB gain block; no
    public netlist exists) and use it in rx_amp
    - LTC6268-10: ADI publishes only an LTspice model, so the datasheet-based
    two-pole macromodel is kept (documented in sim/README.md)
    - Update RESULTS/summarize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
2026-09-14 Add end-to-end system simulations and TX architecture notes
    - sim/system/: tx_chain, tx_chain_fca, rx_chain (+noise), link, link_tran
    - sim/models/: reusable board subcircuits (preemphasis, tx_amp, fca,
    led_board, rx_amp)
    - Run the full chain with 50 ohm interfaces and an optical K factor
    - Document the TX architecture recommendation in docs/INTEGRACION_MODULAR.md
    and sim/README.md (single driver, digital pre-emphasis, current-mode driver)
2026-09-14 Model the LED-board bias-tee as an explicit block in the system sims
    - Add sim/models/bias_tee.sub (C1/C2 + L1) and led_equiv.sub
    - tx_chain, tx_chain_fca, link, link_tran now chain driver -> BIAS_TEE -> LED
    - Document the bias-tee passband (~0.7 MHz to ~39 MHz) in sim/README.md and
    docs/INTEGRACION_MODULAR.md
2026-09-14 Correct bias-tee analysis: low corner is set by the choke
    The LED-board bias-tee (L1=206 nH, C=100 nF) is a high-pass with a ~1.45 MHz
    corner dominated by the choke, not a 0.7-39 MHz band-pass. Add an L1 sweep
    (206 nH..47 uH) showing how to lower the corner to ~33-85 kHz.
2026-09-14 Simulate the full link and a parametric LED-PD optical channel
    - sim/system/optical_channel.cir: LOS channel i_pd = K*i_LED with K = K0/D^2
    - sim/system/link_channel.cir: full chain with the parametric optical channel;
    ~2.7 V/V at 50 MHz for D = 0.5 m (a 50 MHz channel)
    - scripts/sweep_optical_distance.py: distance sweep (0.1..2 m), 1/D^2 verified
    - Add both decks to run_all_sims.sh and the results summary
2026-09-15 Add VLC link budget and distance-improvement guide
    - scripts/vlc_link_budget.py: LOS link budget, SNR and reachable distance
    (bare PD ~6 cm at 50 MHz/10 dB SNR; 25 mm lens ~1 m; APD+lens ~7 m)
    - docs/VLC_ALCANCE.md: priorities to extend range and the impedance question
    (TX current-mode match to the LED, RX resonate the PD capacitance, narrowband)
    - Parameterise the optical collection gain (G) in the channel decks
